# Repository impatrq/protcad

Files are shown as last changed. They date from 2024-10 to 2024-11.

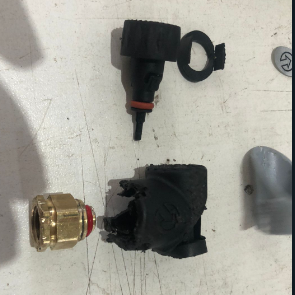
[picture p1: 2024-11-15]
Captura de pantalla 2024-11-15 102701.png

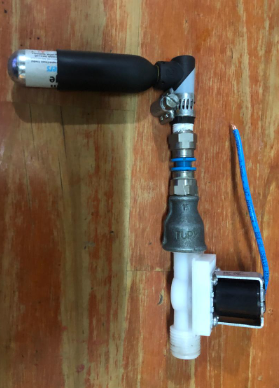
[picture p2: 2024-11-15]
Captura de pantalla 2024-11-15 101422.png

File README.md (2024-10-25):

# protcad

PRESENTACION DEL PROYECTO:

Es un proyecto, desarrolamos un sistema de seguridad automatico,
pensado principalmente para adultos mayores, para personals en
reabilitacion, o que sufren de anguna enfermedad o son epilepticos
es un chaleco tipo airbag que amortigua las caidas al inflarse

roblemas clave: 
Lesiones Graves / Muerte: Las caídas pueden resultar en fracturas y otros daños que limitan la movilidad y la independencia. 
Miedo y Ansiedad: Muchas personas mayores y sus familias viven con el miedo constante de que una caída pueda causar un accidente grave. 
Dependencia Aumentada: Después de una caída, algunas personas necesitan más ayuda, lo que puede afectar su autonomía. 
Costos Médicos: Las lesiones por caídas generan gastos altos en tratamientos médicos y hospitalizaciones. 
 
 Lesiones: Aproximadamente el 30-40% de las personas mayores de 65 años sufren caídas anualmente, y un porcentaje considerable de estas caídas resultan en lesiones. 
Muertes: Las caídas son una de las principales causas de muerte accidental en personas mayores. En Estados Unidos, por ejemplo, se estima que alrededor de 36,000 personas mayores mueren anualmente debido a caídas. 

La solucion que ofrece ProtCad

1. deteccion rapida de las caidas 
Utiliza el sensor MPU6050 para monitorear continuamente la posición y aceleración del usuario. Al detectar una inclinación que indica una caída, el sistema se activa de inmediato.
2. Inflado Automático del Airbag:
Al activarse, un cartucho de CO2 infla rápidamente una bolsa protectora alrededor de áreas vulnerables, como la cadera, amortiguando el impacto y reduciendo el riesgo de lesiones graves.
3. Protección de Áreas Críticas:
El diseño del chaleco está enfocado en proteger las zonas más susceptibles a fracturas, lo que ayuda a prevenir lesiones graves en caso de caídas.
4. Tranquilidad para Usuarios
proporciona seguridad tanto al usuario como a sus familiares, aliviando la ansiedad relacionada con las caídas y fomentando la independencia en las actividades diarias.

OBJETIVOS:
Dar protección, seguridad, minimizar el riesgo de lesiones graves por caídas en personas mayores y con condiciones de movilidad reducida, mejorando así su seguridad y calidad de vida.

1. Prevención de Lesiones:Que nuestros usuarios puedan tener una mejor calidad de vida.

2. Detección Precisa de Caídas: Tener un sistema seguro y con la mejor presicion.

3. Facilitar la Independencia.

4. Tranquilidad para Cuidadores y Familiares.

5. Evaluación y Mejora Continua.

Publico Objetivo:

En Argentina el 15,7% de la poblacion son adultos mayores que es nuestro principal interes desp estan las personas en reabilitacion.

El segmento destino de ProtCad se enfoca principalmente en las siguientes 
usuarios:

1. Personas mayores de 40 años: A partir de esta edad, los huesos 
tienden a volverse más frágiles debido a la disminución de la densidad 
ósea y la pérdida de calcio. Esto las hace más vulnerables a fracturas 
graves en caso de caídas, especialmente en la cadera. Este grupo es el 
más susceptible a sufrir consecuencias graves, como dificultades de 
movilidad, pérdida de independencia, o incluso muerte por 
complicaciones derivadas de una fractura de cadera.

2. Personas en rehabilitación: Aquellas que se recuperan de una cirugía 
o lesión y que necesitan protección adicional para evitar recaídas que 
puedan agravar su estado. ProtCad ofrecería una capa extra de 
seguridad durante el proceso de recuperación.

3. Personas con condiciones neurológicas como epilepsia, Parkinson 
o esclerosis múltiple: Estos usuarios están más expuestos a caídas 
debido a problemas de coordinación y equilibrio que son comunes en 
estas condiciones.

4. Personas con enfermedades crónicas como osteoporosis o diabetes 
con neuropatía periférica: Estas condiciones incrementan el riesgo 
de fracturas o lesiones graves en caso de caídas, lo que convierte a ProtCad en una herramienta de protección valiosa para evitar daños mayores.

5. Personas que cuidan a sus seres queridos: Además de los usuarios directos, este segmento incluye a quienes tienen a su cargo personas mayores o con discapacidades, y que buscan mejorar la seguridad y reducir la ansiedad de cuidar a alguien vulnerable a caídas.

En resumen, ProtCad está dirigido a personas de mediana edad y mayores, así como a aquellos con condiciones médicas específicas que los hacen más propensos a sufrir caídas y lesiones severas.

* COSTOS:   

En Japon venden este producto por su gran poblacion de adultos mayores, en europa y Estados unidos tambien, en argentina sale aprox   $ 1.000.000
![]() 

Descripcion Tecnica:
 
Sensores principales que utilizamos: 

* MPU6050: Cuenta con un giroscopo con 3 ejes y un acelerometro de 3 ejes.
* RASPBERRY PICO: Trabajamos con un codigo de lenguaje en C.

FIN.

Lo visto como presentacion es lo que se encuentra ya en un archivo y se presento en la oniet y se presentara en proximas esposiciones en su formato como power point.

A continuacion la siguiente INFORMACION tambien se encuetra en el informe descriptivo

ALCANCE DE PROTCAD:

Alcance: Delimitar el proyecto, y describir de qué trata:
PROTCAD es un chaleco de protección, diseñado para minimizar el impacto 
de caídas y prevenir lesiones graves. El chaleco se activa automáticamente al 
detectar una caída, inflándose de inmediato para proteger áreas clave.
Limitaciones del proyecto:
1. Tamaño único por el momento: Aunque adaptable, actualmente el 
chaleco está disponible en un solo talle general.
2. Enfoque en usuarios específicos: Está dirigido principalmente a 
personas con riesgo de caídas, lo que limita su adopción masiva en 
personas fuera de estos grupos.
3. Costo: El precio de producción estimado es de 140 mil pesos, lo que 
podría limitar su accesibilidad a ciertos mercados.
El proyecto, aunque en sus fases iniciales, tiene el potencial de ser mejorado 
con más recursos y tiempo, permitiendo una mayor adaptabilidad y una posible 
expansión hacia otros sectores o mercados más amplios.

. Temática o Impacto de PROTCAD: Bienestar y Salud / Inovacion

* Impacto Social:

PROTCAD tiene un enfoque directo en la seguridad personal y el bienestar
de personas vulnerables, brindando protección a quienes tienen un mayor riesgo 
de sufrir caídas, como adultos mayores, personas en rehabilitación, y aquellos 
con condiciones médicas que afectan su movilidad. 

Su impacto social es significativo por varias razones:
1. Prevención de lesiones graves: Al reducir el riesgo de fracturas o daños 
en la cabeza, la columna y la cadera, PROTCAD contribuye a mejorar la 
salud y calidad de vida de los usuarios, disminuyendo las posibles 
secuelas físicas de una caída.
2. Tranquilidad para el usuario y su entorno: Muchas personas, 
especialmente familiares o cuidadores, viven con la constante 
preocupación de que un ser querido sufra una caída grave. PROTCAD 
ofrece una solución que genera confianza y paz mental tanto para los 
usuarios como para sus seres cercanos.
3. Mejor calidad de vida: El chaleco permite que los usuarios mantengan 
su independencia y realicen sus actividades cotidianas sin temor a sufrir 
un accidente. Esto es crucial para mantener la autonomía y reducir la 
dependencia de terceros, lo cual es particularmente importante para 
personas mayores.
4. Inclusión: PROTCAD se dirige a diversos grupos que enfrentan 
dificultades diarias debido a su condición física, creando un dispositivo 
que ayuda a mejorar la seguridad y el movimiento, dándoles una mayor 
oportunidad de participación en la sociedad.

{Creado en china, desarrollado en EE. UU, disponibles en mercados europeos, america del norte, en Italia, Se espera que su adopción aumente a medida que se vuelvan más accesibles, particularmente en sociedades que envejecen como Japón, Estados Unidos y partes de Europa.}

* Impacto Geográfico 

El impacto geográfico de PROTCAD puede ser relevante tanto a nivel local como global:

1. Impacto Nacional: El proyecto es una innovación que, hasta ahora, no ha sido producida ni distribuida a nivel nacional. Al implementarse en un mercado local, podría cubrir una necesidad significativa en países o regiones con poblaciones envejecidas o con altos índices de 
enfermedades crónicas que afectan la movilidad, como ocurre en muchos países latinoamericanos, incluido Argentina.

2. Impacto Global: A largo plazo, PROTCAD tiene potencial para 
expandirse internacionalmente, ya que el envejecimiento de la población es una tendencia mundial, y con ello aumenta el riesgo de caídas y 
lesiones graves. Países con un mayor porcentaje de personas mayores, como
Japón o algunos países de Europa, serían mercados donde este tipo de
tecnología podría tener una alta demanda.

* Otros Impactos Potenciales

• Sector salud: PROTCAD puede reducir la demanda en los sistemas de 
salud pública y privada al disminuir el número de hospitalizaciones 
relacionadas con caídas, fracturas y cirugías resultantes de accidentes en 
personas mayores o en rehabilitación.
• Innovación tecnológica: Al ser un producto que involucra tecnología 
avanzada (sensores, válvulas, CO2), PROTCAD impulsa la innovación
en el campo de los dispositivos de seguridad personal, contribuyendo al 
desarrollo de nuevos productos que podrían aplicarse en otras áreas o 
grupos.

En resumen, el impacto de PROTCAD es amplio tanto a nivel social como geográfico, ofreciendo una solución que responde a una necesidad urgente en la prevención de lesiones graves por caídas, con el potencial de beneficiar a individuos y sistemas de salud tanto local como globalmente

* Segmento destino (target)

El segmento destino de ProtCad se enfoca principalmente en las siguientes 
usuarios:

1. Personas mayores de 40 años: A partir de esta edad, los huesos 
tienden a volverse más frágiles debido a la disminución de la densidad 
ósea y la pérdida de calcio. Esto las hace más vulnerables a fracturas 
graves en caso de caídas, especialmente en la cadera. Este grupo es el 
más susceptible a sufrir consecuencias graves, como dificultades de 
movilidad, pérdida de independencia, o incluso muerte por 
complicaciones derivadas de una fractura de cadera.

2. Personas en rehabilitación: Aquellas que se recuperan de una cirugía 
o lesión y que necesitan protección adicional para evitar recaídas que 
puedan agravar su estado. ProtCad ofrecería una capa extra de 
seguridad durante el proceso de recuperación.

3. Personas con condiciones neurológicas como epilepsia, Parkinson 
o esclerosis múltiple: Estos usuarios están más expuestos a caídas 
debido a problemas de coordinación y equilibrio que son comunes en 
estas condiciones.

4. Personas con enfermedades crónicas como osteoporosis o diabetes 
con neuropatía periférica: Estas condiciones incrementan el riesgo 
de fracturas o lesiones graves en caso de caídas, lo que convierte a 
ProtCad en una herramienta de protección valiosa para evitar daños 
mayores.

5. Personas que cuidan a sus seres queridos: Además de los usuarios 
directos, este segmento incluye a quienes tienen a su cargo personas 
mayores o con discapacidades, y que buscan mejorar la seguridad y 
reducir la ansiedad de cuidar a alguien vulnerable a caídas.
En resumen, ProtCad está dirigido a personas de mediana edad y mayores, así 
como a aquellos con condiciones médicas específicas que los hacen más 
propensos a sufrir caídas y lesiones severas.

* Ámbito de incumbencia (entorno donde se desarrolla) 

El ámbito de incumbencia de ProtCad se centra en varios entornos 
clave donde este producto podría desarrollarse y tener impacto:

1) Sector de la salud y rehabilitación: ProtCad se inserta dentro 
de la atención médica preventiva, especialmente en centros de 
rehabilitación, hospitales, y clínicas donde se tratan personas 
con condiciones físicas que las hacen propensas a caídas, como 
pacientes geriátricos o aquellos en procesos postoperatorios. 
Además, tiene cabida en instituciones especializadas en 
neurología para personas con Parkinson, epilepsia o esclerosis 
múltiple.
2) Hogares de cuidado de ancianos y residencias geriátricas: 
Los hogares de cuidado, donde la preocupación por caídas es 
alta, son un entorno esencial para la implementación de 
ProtCad. En estos espacios, los cuidadores y personal médico 
buscan maneras de mejorar la seguridad de las personas 
mayores, y este tipo de tecnología sería un complemento ideal 
para reducir riesgos.
3) Entornos domésticos: Para personas que envejecen en sus 
propios hogares, el chaleco ProtCad ofrece una solución práctica 
para mejorar su seguridad diaria sin comprometer la 
independencia. Familias que cuidan a personas mayores o con 
movilidad reducida podrían implementar el producto como una 
medida preventiva.
4) Mercado de dispositivos de asistencia personal y tecnología 
vestible (wearables): En el contexto de la tecnología aplicada a 
la salud, ProtCad se integra dentro del mercado de los wearables 
o dispositivos inteligentes de protección. Este tipo de chaleco 
airbag, que combina sensores avanzados con mecanismos 
automáticos de inflado, puede atraer a personas que buscan 
productos de alta tecnología para mejorar su calidad de vida.
5) Industrias de protección laboral: Aunque inicialmente se 
piensa en el sector de la salud, el ámbito laboral para 
trabajadores de ciertos sectores (construcción, agricultura, etc.) 
donde el riesgo de caídas es alto también es relevante. ProtCad 
podría adaptarse a estos entornos, brindando seguridad adicional 
a los trabajadores.

En resumen, el entorno donde se desarrolla el proyecto abarca el 
ámbito sanitario, los hogares de cuidado, y el mercado de 
dispositivos de protección personales, con la posibilidad de 
expandirse a sectores laborales.

Descripción general (Explicar el proyecto) 
ProtCad es un proyecto innovador que busca desarrollar un chaleco (en 
principio era un cinturon) de protección tipo airbag, diseñado para activarse en 
el momento de una caída. Este dispositivo está pensado principalmente para 
personas mayores o con condiciones médicas que las hagan propensas a caídas, 
como osteoporosis, Parkinson o problemas de movilidad. El sistema se activa a 
través de un sensor de movimiento (MPU6050), que detecta la inclinación de la 
persona y libera aire comprimido para inflar una bolsa que protege la cadera y 
otras áreas críticas del cuerpo. El objetivo principal es reducir el impacto y el
riesgo de lesiones graves, proporcionando seguridad y tranquilidad a los 
usuarios y sus familias.

AREA ELECTRONICA (PROGRAMACION)

linea de codigo usada y probada (funciona) 

#include <stdio.h>
#include <math.h>
#include "pico/stdlib.h"
#include "mpu6050.h"

#define SDA_GPIO  4
#define SCL_GPIO  5 
#define LED_PIN_X 14 // Led rojo - Eje XW
#define LED_PIN_Y 15 // Led verde - Eje Y
#define LED_PIN_VALVE 13 // Valvula de agua
#define X_LIMIT 30.20 // Límite de inclinación para el eje X
#define Y_LIMIT 30.20 // Límite de inclinación para el eje Y

int main(void)
{  
    stdio_init_all();
    sleep_ms(1000);

    printf("Inicializando I2C...\n");

    // Inicializacion de I2C
    i2c_init(i2c0, 400000);
    gpio_set_function(SDA_GPIO, GPIO_FUNC_I2C);
    gpio_set_function(SCL_GPIO, GPIO_FUNC_I2C);
    gpio_pull_up(SDA_GPIO);
    gpio_pull_up(SCL_GPIO);

    printf("Inicializando MPU6050...\n");

    // Inicializacion de MPU6050
    mpu6050_init(i2c0, 0x68);
    sleep_ms(2000);

    printf("Who am I = 0x%2x\n", mpu6050_who_am_i());

    // Configuración de los LEDs como salidas
    gpio_init(LED_PIN_X);
    gpio_init(LED_PIN_Y);
    gpio_set_dir(LED_PIN_X, GPIO_OUT);
    gpio_set_dir(LED_PIN_Y, GPIO_OUT);
    gpio_init(LED_PIN_VALVE);
    gpio_set_dir(LED_PIN_VALVE, GPIO_OUT);

    while (true) {

        // Estructura para datos de aceleracion
        mpu_accel_t accel = {0};
        mpu_gyro_t gyro = {0};
        int16_t temp = 0;

        // Leo MPU
        mpu6050_read_accel(&accel);
        mpu6050_read_gyro(&gyro);
        mpu6050_read_temp(&temp);

        // Convertir aceleracion a G(gravedad)
        float ax = (9.81 * (accel.accel_x / 33678.0));
        float ay = (9.81 * (accel.accel_y / 32768.0));
        float az = (9.81 * (accel.accel_z / 32768.0));

        //Calcular los angulos de inclinacion
        float accel_ang_x = atan(ax / sqrt(pow(ay, 2) + pow(az, 2))) * (180.0 / 3.14);
        float accel_ang_y = atan(ay / sqrt(pow(ax, 2) + pow(az, 2))) * (180.0 / 3.14);
        // Muestro valores de aceleracion y angulos de inclinacion
        printf("Ax = %.2f, Ay = %.2f, Az = %.2f\n", ax, ay, az);
        printf("Inclinacion en X: %.2f\tInclinacion en Y: %.2f\n", accel_ang_x, accel_ang_y);
        printf("Temp = %d\n", temp);

        // Verificar si la inclinación en X supera el límite y controlar el LED rojo
        bool led_x_on = fabs(accel_ang_x) > X_LIMIT;
        gpio_put(LED_PIN_X, led_x_on);

        // Verificar si la inclinación en Y supera el límite y controlar el LED verde
        bool led_y_on = fabs(accel_ang_y) > Y_LIMIT;
        gpio_put(LED_PIN_Y, led_y_on);

        // Controlar la válvula: se abre si cualquier LED está encendido
        if (led_x_on || led_y_on) {
            gpio_put(LED_PIN_VALVE, 1);  // Abrir la válvula
        } else {
            gpio_put(LED_PIN_VALVE, 0);  // Cerrar la válvula
        }

        // Pausa de 100 ms entre lecturas
        sleep_ms(1000);
    }
}

Protcad es un chaleco de seguridad tipo airbag que se infla al reconocer que el usuario se esta por caer. Esta dirigido a personas en rehabilitacion, gente mayor, y personas que sufran algun tipo de condicion propensa a sufrir caidas. El sistema consta de un sensor MPU6050 acelerometro y giroscopo que sensa constantemente la condicion del chaleco, en el segundo que la persona se cae, este manda una señal que activa un sistema de abertura de cartuchos de aire comprimido que inflan el airbag que se encuentra dentro del chaleco, haciendo que este este quede totalmente inflado y pueda reducir considerablemente el impacto de la persona contra el suelo

FUNCIONALIDADES Y BENEFICIOS: 

 Funcionalidades (Qué hace?)  

Detección de Caídas: Utiliza un sensor MPU6050 que funciona como giróscopo y acelerómetro para detectar cambios en la posición del usuario, estos son monitoreados continuamente. Cuando el sensor detecta una inclinación que supera los límites predefinidos (indicando una posible caída), activa el sistema de protección. 

Activación Automática del Airbag: Al detectar una caída, el sistema abre un cartucho de aire comprimido que infla rápidamente una bolsa alrededor de la cadera, amortiguando el impacto y reduciendo el riesgo de lesiones graves. 

Protección de Zonas Vulnerables: El diseño del chaleco está enfocado en proteger principalmente la cadera, una de las áreas más susceptibles a fracturas en personas mayores o con movilidad reducida, pero también ofrece protección a otras zonas del cuerpo según el diseño. 

Indicadores Visuales: Dispone de luces LED para indicar el estado del dispositivo y alertar sobre el funcionamiento del sensor, mostrando si un eje (X, Y o Z) ha superado los límites de inclinación. 

Botón de Encendido y Apagado: Para mayor control, el usuario puede activar o desactivar el dispositivo cuando lo considere necesario. 

Beneficios (Por qué es bueno el proyecto?)  

1. Prevención de Lesiones: Al proporcionar un sistema de protección tipo airbag que se activa durante una caída, ProtCad reduce significativamente el riesgo de fracturas en la cadera y otras lesiones graves en personas mayores o con problemas de movilidad, evitando hospitalizaciones prolongadas y complicaciones de salud. 

2. Mayor Seguridad y Tranquilidad: Al proteger áreas vulnerables como la cadera, brinda seguridad tanto al usuario como a su entorno cercano (familia, cuidadores), aliviando el miedo y la ansiedad relacionados con caídas. 

3. Innovación y Accesibilidad: El uso de sensores y tecnología de inflado rápida permite una solución avanzada y eficiente que no requiere de intervenciones médicas complicadas. Además, su diseño adaptable lo hace accesible para una amplia gama de personas. 

4. Mejora de la Calidad de Vida: Al reducir el impacto de las caídas, ProtCad permite que las personas mayores o en rehabilitación puedan moverse con más libertad, confianza e independencia, promoviendo una vida más activa y saludable. 

5. Costo Eficiente: En comparación con los costos médicos de tratar fracturas y otros daños, el uso preventivo de ProtCad es una inversión rentable a largo plazo para evitar gastos médicos elevados.

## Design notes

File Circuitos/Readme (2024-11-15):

En esta carpeta se encuentra todo lo relacionado a circuitos

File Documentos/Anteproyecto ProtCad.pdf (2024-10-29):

# ProtCad

# Anteproyecto

# Título de proyecto:

El nombre “ProtCad” es una abreviación del nombre “Protección de Cadera”

# Integrantes:

- Micaela, Lopez Arana
- Dafne, Monzon Matos

# Objetivo del proyecto:

Diseñar y construir un cinturón de protección para personas que, al momento de caerse y recibir un fuerte golpe en la zona de la cadera, se active un sistema que rodee la cadera de la persona con bolsas de aire que amortigüe el cuerpo al momento del impacto.

# Utilidades del proyecto:

ProtCad está derivado a gente arriba de los 45, debido que a partir de esta edad los huesos empiezan a volverse más débiles por la fata de calcio y fosforo. Desde cierta edad, los huesos al estar más débiles sufren desgastes, con una caída podría ocasionar graves lesiones , se ha visto que la cadera es de los lugares del cuerpo que más suelen recibir golpes severos.

Recibir un golpe en esta zona puede causar:

- Dolor muscular
- Dificultad para caminar, perdida de movilidad

- Perdida de independencia
- Lesiones
- Acortar la vida
- La muerte

Los golpes en esta zona son los más recurrentes y uno de los más serios, puede causar una gran problemática en la vida diaria tanto para la persona como para quienes la rodean. Aunque esto se dedica a alguien mayor de 45 años, se espera un mayor uso en personas con problemas al caminar (con mayor índice de posibles caídas), en su momento se espera que se pueda actuar y asegurar que la persona no sufrió daños severos.

Nuestro proyecto busca dar seguridad a quien lleve este cinturón, confiando y buscando tener en cuenta la comodidad y confianza del individuo, a su vez buscamos aligerar el estrés de la persona y de quienes lo rodeen y evitar daños a futuro en quienes lo utilicen.

# Descripción del funcionamiento:

Lo fundamental en este proyecto, es el sensor MPU6050 que vamos a usar como giróscopo, así pudiendo determinar los puntos de caída que tiene una persona gracias a sus tres ejes (X, Y, Z).

Se divide en dos partes, el circuito de detección del sensor mpu6050, y el sistema que abre el cartucho de aire para que se infle el cinturón.

Se piensa usar Raspberry pi pico o ver de usar un ESP32 que podria tener mas desarrollo.

Parte del Sensor MPU6050:

Primero conectamos el sensor al microcontrolador y a su vez conectamos 3 leds de diferente color (rojo, verde, azul) para diferencias los ejes del sensor (Y, X, Z), los cuales también tienen una resistencia de 100 ohms cada uno.

Ajustando en el código del sensor, se definen los límites de los grados de cada eje, los leds aparte de servir para diferenciar cada eje se van a activar siempre que un eje supere su límite de grados, por ejemplo, si el eje Y supera los -10° se va a encender el led verde, si el eje X los supera, se va a encender el led azul, y si el eje Z los supera, se va a encender el led rojo. Esto se toma como una ayuda para poder ir definiendo los límites del sensor y cómo reacciona ante los movimientos y las diferentes posiciones que se pueden tener.

Parte del cartucho de aire:

El sistema que se piensa crear es un motor dc n20 para que al girar accione una aguja que se mueva unos pocos centímetros hasta perforar la tapa de un cartucho de aire que al liberarse la tapa se infle instantáneamente el protector de cadera (echa de nylon y cubierta de tela para mayor seguridad).

Para esto se piensa tal vez usar a su vez otro motor que active otra válvula de aire, ya que se emplearan dos válvulas de aire para llenar todo el protector y no solo una, a su vez existe la posibilidad de usar un solo motor buscando la manera de perforar más de un cartucho.

Conjunto de ambas partes:

En esta parte tenemos que unir ambos espacios, definiendo que cuando un led se encienda indicando que la persona sobrepaso el límite de grados(caerse) active el motor dc n20 y abra el cartucho dejando que el protector se llene por completo y pueda amortiguar la caída de dicha persona. Después de programar el sensor MPU6050 a su vez se ira programando el motor Dc20, pero se separa en partes para una mejor organización por más que esto se trabaje en conjunto.

Cinturón:

Se usará un cinturón que se pueda abrochar a la altura de la cadera o el ombligo y sea posible ajustarlo o desajustarlo, estará compuesto con bolsas de nylon rodeando un poco la cadera y un compartimiento para el circuito con su respectiva fuente recargable, y los compartimientos para los cartuchos de aire que trataran de ser cambiables.

# Análisis de factibilidad:

Se cuenta con herramientas y conocimientos básicos para realizar este proyecto, también se considera la falta de conocimiento muy importante en este tema, habiendo investigado se pudo finalizar que la información que nos falta está disponible para investigación y explicación en lo que necesitemos, al igual que los seguros problemas que surjan en este tramo se espera contar con el apoyo de los profesores en cuestión de dudas y recomendaciones.

Todos los integrantes del grupo trabajaran en los mismos campos de trabajo constantemente, pero se podría tener una guía de que haría cada uno:

Micaela Lopez Arana:

.Se encargara de la programación del Sensor MPU6050

.Investigación de los cartuchos de Co2 en conjunto con el airbag necesario

.Diseño de planos de placas , PCB y realización de circuitos, de motor mpu6050 su diseño de circuito electronico

.Creación de cuentas de correo electronico

.Creacion y ensamblaje principal del cinturon, su diseño

. Informes/registro: en formato borrador de los procesos que se realizan para tener su registro y proceso durante el año.

Dafne Monzon Matos:

.Redactar el manual de usuario: los borradores del proceso del proyecto durante el año eh informes diarios del progreso de el mismo para tener un registro, y a fin de año un manual final que sería el oficial.

. Programación del motor en conjunto al Sensor MPU6050, ósea su programación y ensamblaje con la otra parte del sensor mpu6050

. impresión de piezas 3D: de ser necesarias, y ayuda con la obtención o compras de componentes

. Creación del logo (en conjunto), distintivos y ej: remeras

. Marketing: diseño y creación de las páginas web, publicidad en redes sociales con información sobre ProdCad

. Ensamblaje de componentes: ayuda con la creacion del cinturon y soldadura de placas etc

. Guia grafica de procesos a hacer durante el año y desarrollo de procesos

# Costo del proyecto:

Componente | Precio | Disponible
2 sensores MPU6050 | 2.000$ 5.000$ | Si
Rapberry Pi Pico | | Si
Protoboard | 2.000$ 3.000$ | Si
Modulo Rele 2 Canales | 5.000$ 8.000$ | Si
Tres resistencias de 100 ohms | 1.000$ 2.000$ | Si
Motor Dc N20 | 4.000$ 6.000$ | Si
Power Bank | 20.000$ | Si
Nylon | | Si
Jumpers | 2.000$ 3.000$ | Si
3 leds | | Si

Costo total aproximado del proyecto:

- 50.000$(Sumando el valor mas caro)
- 65.000$(Agregando componentes propios)

Todos estos productos fueron buscados en Mercado Libre para una mejor referencia, aun asi se pueden encontrar lugares que reducirían el costo de muchos de estos productos, pudiendo así reducir el costo total del proyecto.

# Referencias:

- https://www.google.com/url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 (https://www.todomicro.com.ar/arduino/176-acelerometro-y-giroscopio-mpu-6050.html)
- https://articulo.mercadolibre.com.ar/MLA-1406668761-sensor-modulo-acelerometrogiroscopio-6-ejes-mpu6050-arduino-_JM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 (https://articulo.mercadolibre.com.ar/MLA-1406668761-sensor-modulo-acelerometro-giroscopio-6-ejes-mpu6050-arduino-_JM)
- https://www.mercadolibre.com.ar/placa-desarrollo-raspberry-pi-pico-w-rp2040-conwifi/p/MLA34289250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 (https://www.mercadolibre.com.ar/placa-desarrollo-raspberry-pi-pico-w-rp2040-con-wifi/p/MLA34289250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)
- https://www.mercadolibre.com.ar/placa-experimental-protoboard-830-puntos-arduinoelectronica/p/MLA27915857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 (https://www.mercadolibre.com.ar/placa-experimental-protoboard-830-puntos-arduino-electronica/p/MLA27915857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)
- https://articulo.mercadolibre.com.ar/MLA-927644290-modulo-relay-rele-2-canalesoptoacoplado-12v-arduino-hobb-_JM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 (https://articulo.mercadolibre.com.ar/MLA-927644290-modulo-relay-rele-2-canales-optoacoplado-12v-arduino-hobb-_JM)
- https://articulo.mercadolibre.com.ar/MLA-1103567839-placa-uno-r3-compatible-arduinocon-cable-usb-zocalo-emakers-_JM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 (https://articulo.mercadolibre.com.ar/MLA-1103567839-placa-uno-r3-compatible-arduino-con-cable-usb-zocalo-emakers-_JM)
- https://articulo.mercadolibre.com.ar/MLA-818043421-micro-motor-dc-n20-6v-150rpm-cajareductara-de-6-y-9-volts-
_JM#position=1&search_layout=stack&type=item&tracking_id=31fb140b-bdcf-461a-bea2-0461aada1989 (https://articulo.mercadolibre.com.ar/MLA-818043421-micro-motor-dc-n20-6v-150rpm-caja-reductara-de-6-y-9-volts-_JM)
- https://www.googleadservices.com/pagead/aclk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 &nis=4&ved=2ahUKEwjojJv544CFAxVJqZUCHdj3DfAQ9aACKAB6BAgGEA4&adurl= (https://www.googleadservices.com/pagead/aclk?ai=DChcSEwi_yqH544CFAxWQVUgAHdOiBd8YABANGgJjZQ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)
•
https://click1.mercadolibre.com.ar/mclics/clicks/external/MLA/count?a=UDXSVn%2FZkwXy R3hEv8h4uI6eb0hvr4wp6JGYo6mJPxU7duOto0YVYI4Fg3RKyLkVDaaylWY%2BvATzvDrpOp7w qgN4kYRY31r%2BW%2FS7Z2NAj0HuG8OcQPAf%2FMeH4H4cZHT%2BuxcbSW4zIhrUNAKnl4 DaUwOlQjmrRHqkb8bNs8cIUJacIlyXRc38ylIsxCJWRaH5KeAT03BN9Yu%2FvjaOsqHGm0RoFsp az9ADJKc4B7wlQGKspVq3L8QSU1OHzzyWY8aZsU%2B2zsvP0DvvS0gGhGe6HluF0ZkFMG%2F vO0p6dZYz%2FRhwXZ57V%2FcLRq0bBc33cUAXwPLK7aKSYW6m76y9wpvvEoDlw9d5g9D4oG rJIrRerI4HBQdkyM%2BNzecPLJgar3CZ3gkDsmvUPKQgwjZ7pb4Q4CbjbYt1A%2FjfG3Qut5faEn (https://click1.mercadolibre.com.ar/mclics/clicks/external/MLA/count?rb=x)

sb4IcwccvO72Jzm3i5z49dZ0ubg4K1yc4c0qiglw2MiG7AKe3KSvtoti3jZdxN8rovZBPOP9dibCsBv VKqXFkZlBQuNQ9oNSVtpUmkqUbUIbUNk%2BzurhJYMwMG6tJyo7SI6KWdBAbKGAvdbZx3jH S6A7vVoPGe3uOzypS5xHZnAfSIjzyhOmNZDQGFmx0I0pv1Ltz70tXO1XDGYDsteqJd0UaJERzCu Ja7KUYy0upD8Xh5YjLswevH61we1c607g4rwHa6xl3kXkwxDBe%2FHJD4d91YR44vkS%2F1Qt0 %3D&e=mclics%2Fgtins%2B17001%2Cmclics%2Fadvertising-results-augmenteron%2B15098%2Cmclics%2Fvariant-candidates%2B31710%2Cmclics%2Fsearch-list-adalgorithm%2BDEFAULT%2Cmclics%2Fmax-bid-capped%2B36383%2Cmclics%2Fmax-biditem-factor%2B23927%2Cmclics%2Fpads-score-mla%2B17263%2Cmclics%2Flax-topdomain%2B23443&rb=x (https://click1.mercadolibre.com.ar/mclics/clicks/external/MLA/count?rb=x)
•

# Analisis de costo/beneficio:

Este proyecto esta derivado a gente mayor de 40 años, que es la edad en adelante en las que los huesos se empiezan a volver más débiles siendo propenso a más riesgos. Puede ser usado por quien lo crea adecuado si lo necesita, gracias a eso puede ser usado por una gran variedad de personas para poder protegerse de una forma mas segura para evitar riesgos, como personas en rehabilitacion, personas con huesos debiles y demas. Si bien tiene que tener un cierto campo de uso, no tendria restriccion en cuestion de quien desee utilizarlo.

# Diagrama de bloques del prototipo:

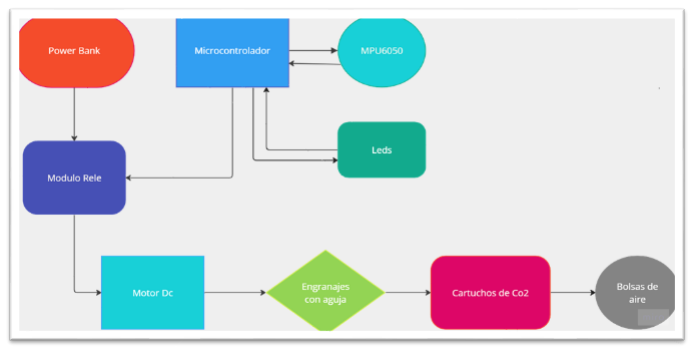
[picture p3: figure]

# Diagrama de tiempo de desarrollo:

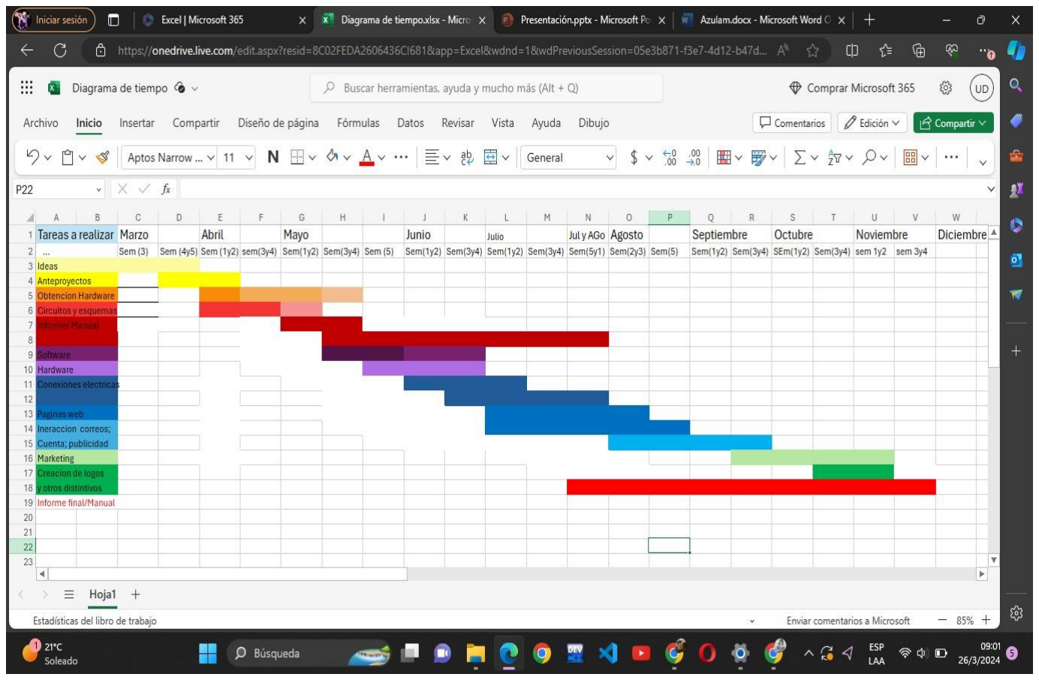
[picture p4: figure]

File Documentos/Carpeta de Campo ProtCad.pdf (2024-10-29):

# CARPETA DE CAMPO

# ProtCad

## Proyecto de 7mo

## IMPA

## Integrantes:

## Lopez Arana Micaela

## Monzon Matos Dafne

# ProtCad

# Anteproyecto

# Título de proyecto:

El nombre “ProtCad” es una abreviación del nombre “Protección de Cadera”

# Integrantes:

- Micaela, Lopez Arana
- Dafne, Monzon Matos

# Objetivo del proyecto:

Diseñar y construir un cinturón de protección para personas que, al momento de caerse y recibir un fuerte golpe en la zona de la cadera, se active un sistema que rodee la cadera de la persona con bolsas de aire que amortigüe el cuerpo al momento del impacto.

Utilidades del proyecto:ProtCad está derivado a gente

arriba de los 45, debido que a partir de esta edad los huesos empiezan a volverse más débiles por la fata de calcio y fosforo. Desde cierta edad, los huesos al estar más débiles sufren desgastes, con una caída podría ocasionar graves lesiones , se ha visto que la cadera es de los lugares del cuerpo que más suelen recibir golpes severos.

Recibir un golpe en esta zona puede causar:

- Dolor muscular
- Dificultad para caminar, perdida de movilidad
- Perdida de independencia
- Lesiones
- Acortar la vida

- La muerte

Los golpes en esta zona son los más recurrentes y uno de los más serios, puede causar una gran problemática en la vida diaria tanto para la persona como para quienes la rodean. Aunque esto se dedica a alguien mayor de 45 años, se espera un mayor uso en personas con problemas al caminar (con mayor índice de posibles caídas), en su momento se espera que se pueda actuar y asegurar que la persona no sufrió daños severos.

Nuestro proyecto busca dar seguridad a quien lleve este cinturón, confiando y buscando tener en cuenta la comodidad y confianza del individuo, a su vez buscamos aligerar el estrés de la persona y de quienes lo rodeen y evitar daños a futuro en quienes lo utilicen.

# Descripción del funcionamiento:

Lo fundamental en este proyecto, es el sensor MPU6050 que vamos a usar como giróscopo, así pudiendo determinar los puntos de caída que tiene una persona gracias a sus tres ejes (X, Y, Z).

Se divide en dos partes, el circuito de detección del sensor mpu6050, y el sistema que abre el cartucho de aire para que se infle el cinturón.

Se piensa usar Raspberry pi pico o ver de usar un ESP32 que podria tener mas desarrollo.

Parte del Sensor MPU6050:

Primero conectamos el sensor al microcontrolador y a su vez conectamos 3 leds de diferente color (rojo, verde, azul) para diferencias los ejes del sensor (Y, X, Z), los cuales también tienen una resistencia de 100 ohms cada uno.

Ajustando en el código del sensor, se definen los límites de los grados de cada eje, los leds aparte de servir para diferenciar cada eje se van a activar siempre que un eje supere su límite de grados, por ejemplo, si el eje Y supera los -10° se va a encender el led verde, si el eje X los supera, se va a encender el led azul, y si el eje Z los supera, se va a encender el led rojo. Esto se toma como una ayuda para poder ir definiendo los límites del sensor y cómo reacciona ante los movimientos y las diferentes posiciones que se pueden tener.

Parte del cartucho de aire:

El sistema que se piensa crear es un motor dc n20 para que al girar accione una aguja que se mueva unos pocos centímetros hasta perforar la tapa de un cartucho de aire que al liberarse la tapa se infle instantáneamente el protector de cadera (echa de nylon y cubierta de tela para mayor seguridad).

Para esto se piensa tal vez usar a su vez otro motor que active otra válvula de aire, ya que se emplearan dos válvulas de aire para llenar todo el protector y no solo una, a su vez existe la posibilidad de usar un solo motor buscando la manera de perforar más de un cartucho.

Conjunto de ambas partes:

En esta parte tenemos que unir ambos espacios, definiendo que cuando un led se encienda indicando que la persona sobrepaso el límite de grados(caerse) active el motor dc n20 y abra el cartucho dejando que el protector se llene por completo y pueda amortiguar la caída de dicha persona. Después de programar el sensor MPU6050 a su vez se ira programando el motor Dc20, pero se separa en partes para una mejor organización por más que esto se trabaje en conjunto.

Cinturón:

Se usará un cinturón que se pueda abrochar a la altura de la cadera o el ombligo y sea posible ajustarlo o desajustarlo, estará compuesto con bolsas de nylon rodeando un poco la cadera y un compartimiento para el circuito con su respectiva fuente recargable, y los compartimientos para los cartuchos de aire que trataran de ser cambiables.

# Análisis de factibilidad:

Se cuenta con herramientas y conocimientos básicos para realizar este proyecto, también se considera la falta de conocimiento muy importante en este tema, habiendo investigado se pudo finalizar que la información que nos falta está disponible para investigación y explicación en lo que necesitemos, al igual que los seguros problemas que surjan en este tramo se espera contar con el apoyo de los profesores en cuestión de dudas y recomendaciones.

Todos los integrantes del grupo trabajaran en los mismos campos de trabajo constantemente, pero se podría tener una guía de que haría cada uno:

Micaela Lopez Arana:

.Se encargara de la programación del Sensor MPU6050

.Investigación de los cartuchos de Co2 en conjunto con el airbag necesario

.Diseño de planos de placas , PCB y realización de circuitos, de motor mpu6050 su diseño de circuito electronico

.Creación de cuentas de correo electronico

.Creacion y ensamblaje principal del cinturon, su diseño

. Informes/registro: en formato borrador de los procesos que se realizan para tener su registro y proceso durante el año.

Dafne Monzon Matos:

.Redactar el manual de usuario: los borradores del proceso del proyecto durante el año eh informes diarios del progreso de el mismo para tener un registro, y a fin de año un manual final que sería el oficial.

. Programación del motor en conjunto al Sensor MPU6050, ósea su programación y ensamblaje con la otra parte del sensor mpu6050

. impresión de piezas 3D: de ser necesarias, y ayuda con la obtención o compras de componentes

. Creación del logo (en conjunto), distintivos y ej: remeras

. Marketing: diseño y creación de las páginas web, publicidad en redes sociales con información sobre ProdCad

. Ensamblaje de componentes: ayuda con la creacion del cinturon y soldadura de placas etc

. Guia grafica de procesos a hacer durante el año y desarrollo de procesos

# Costo del proyecto:

Componente | Precio | Disponible
2 sensores MPU6050 | 2.000$ 5.000$ | Si

Rapberry Pi Pico | | Si
Protoboard | 2.000$ 3.000$ | Si
Modulo Rele 2 Canales | 5.000$ 8.000$ | Si
Tres resistencias de 100 ohms | 1.000$ 2.000$ | Si
Motor Dc N20 | 4.000$ 6.000$ | Si
Power Bank | 20.000$ | Si
Nylon | | Si
Jumpers | 2.000$ 3.000$ | Si
3 leds | | Si

Costo total aproximado del proyecto:

- 50.000$(Sumando el valor mas caro)
- 65.000$(Agregando componentes propios)

Todos estos productos fueron buscados en Mercado Libre para una mejor referencia, aun asi se pueden encontrar lugares que reducirían el costo de muchos de estos productos, pudiendo así reducir el costo total del proyecto.

# Referencias:

- https://www.google.com/url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 (https://www.todomicro.com.ar/arduino/176-acelerometro-y-giroscopio-mpu-6050.html)
- https://articulo.mercadolibre.com.ar/MLA-1406668761-sensor-modulo-acelerometrogiroscopio-6-ejes-mpu6050-arduino-_JM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 (https://articulo.mercadolibre.com.ar/MLA-1406668761-sensor-modulo-acelerometro-giroscopio-6-ejes-mpu6050-arduino-_JM)
- https://www.mercadolibre.com.ar/placa-desarrollo-raspberry-pi-pico-w-rp2040-conwifi/p/MLA34289250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 (https://www.mercadolibre.com.ar/placa-desarrollo-raspberry-pi-pico-w-rp2040-con-wifi/p/MLA34289250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)
- https://www.mercadolibre.com.ar/placa-experimental-protoboard-830-puntos-arduinoelectronica/p/MLA27915857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 (https://www.mercadolibre.com.ar/placa-experimental-protoboard-830-puntos-arduino-electronica/p/MLA27915857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)
- https://articulo.mercadolibre.com.ar/MLA-927644290-modulo-relay-rele-2-canalesoptoacoplado-12v-arduino-hobb-_JM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 (https://articulo.mercadolibre.com.ar/MLA-927644290-modulo-relay-rele-2-canales-optoacoplado-12v-arduino-hobb-_JM)
- https://articulo.mercadolibre.com.ar/MLA-1103567839-placa-uno-r3-compatible-arduinocon-cable-usb-zocalo-emakers-_JM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 (https://articulo.mercadolibre.com.ar/MLA-1103567839-placa-uno-r3-compatible-arduino-con-cable-usb-zocalo-emakers-_JM)
- https://articulo.mercadolibre.com.ar/MLA-818043421-micro-motor-dc-n20-6v-150rpm-cajareductara-de-6-y-9-volts-
_JM#position=1&search_layout=stack&type=item&tracking_id=31fb140b-bdcf-461a-bea2-0461aada1989 (https://articulo.mercadolibre.com.ar/MLA-818043421-micro-motor-dc-n20-6v-150rpm-caja-reductara-de-6-y-9-volts-_JM)
- https://www.googleadservices.com/pagead/aclk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 &nis=4&ved=2ahUKEwjojJv544CFAxVJqZUCHdj3DfAQ9aACKAB6BAgGEA4&adurl= (https://www.googleadservices.com/pagead/aclk?ai=DChcSEwi_yqH544CFAxWQVUgAHdOiBd8YABANGgJjZQ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)
•
https://click1.mercadolibre.com.ar/mclics/clicks/external/MLA/count?a=UDXSVn%2FZkwXy R3hEv8h4uI6eb0hvr4wp6JGYo6mJPxU7duOto0YVYI4Fg3RKyLkVDaaylWY%2BvATzvDrpOp7w qgN4kYRY31r%2BW%2FS7Z2NAj0HuG8OcQPAf%2FMeH4H4cZHT%2BuxcbSW4zIhrUNAKnl4 DaUwOlQjmrRHqkb8bNs8cIUJacIlyXRc38ylIsxCJWRaH5KeAT03BN9Yu%2FvjaOsqHGm0RoFsp (https://click1.mercadolibre.com.ar/mclics/clicks/external/MLA/count?rb=x)

az9ADJKc4B7wlQGKspVq3L8QSU1OHzzyWY8aZsU%2B2zsvP0DvvS0gGhGe6HluF0ZkFMG%2F vO0p6dZYz%2FRhwXZ57V%2FcLRq0bBc33cUAXwPLK7aKSYW6m76y9wpvvEoDlw9d5g9D4oG rJIrRerI4HBQdkyM%2BNzecPLJgar3CZ3gkDsmvUPKQgwjZ7pb4Q4CbjbYt1A%2FjfG3Qut5faEn sb4IcwccvO72Jzm3i5z49dZ0ubg4K1yc4c0qiglw2MiG7AKe3KSvtoti3jZdxN8rovZBPOP9dibCsBv VKqXFkZlBQuNQ9oNSVtpUmkqUbUIbUNk%2BzurhJYMwMG6tJyo7SI6KWdBAbKGAvdbZx3jH S6A7vVoPGe3uOzypS5xHZnAfSIjzyhOmNZDQGFmx0I0pv1Ltz70tXO1XDGYDsteqJd0UaJERzCu Ja7KUYy0upD8Xh5YjLswevH61we1c607g4rwHa6xl3kXkwxDBe%2FHJD4d91YR44vkS%2F1Qt0 %3D&e=mclics%2Fgtins%2B17001%2Cmclics%2Fadvertising-results-augmenteron%2B15098%2Cmclics%2Fvariant-candidates%2B31710%2Cmclics%2Fsearch-list-adalgorithm%2BDEFAULT%2Cmclics%2Fmax-bid-capped%2B36383%2Cmclics%2Fmax-biditem-factor%2B23927%2Cmclics%2Fpads-score-mla%2B17263%2Cmclics%2Flax-topdomain%2B23443&rb=x (https://click1.mercadolibre.com.ar/mclics/clicks/external/MLA/count?rb=x)
•

# Analisis de costo/beneficio:

Este proyecto esta derivado a gente mayor de 40 años, que es la edad en adelante en las que los huesos se empiezan a volver más débiles siendo propenso a más riesgos. Puede ser usado por quien lo crea adecuado si lo necesita, gracias a eso puede ser usado por una gran variedad de personas para poder protegerse de una forma mas segura para evitar riesgos, como personas en rehabilitacion, personas con huesos debiles y demas. Si bien tiene que tener un cierto campo de uso, no tendria restriccion en cuestion de quien desee utilizarlo.

# Diagrama de bloques del prototipo:

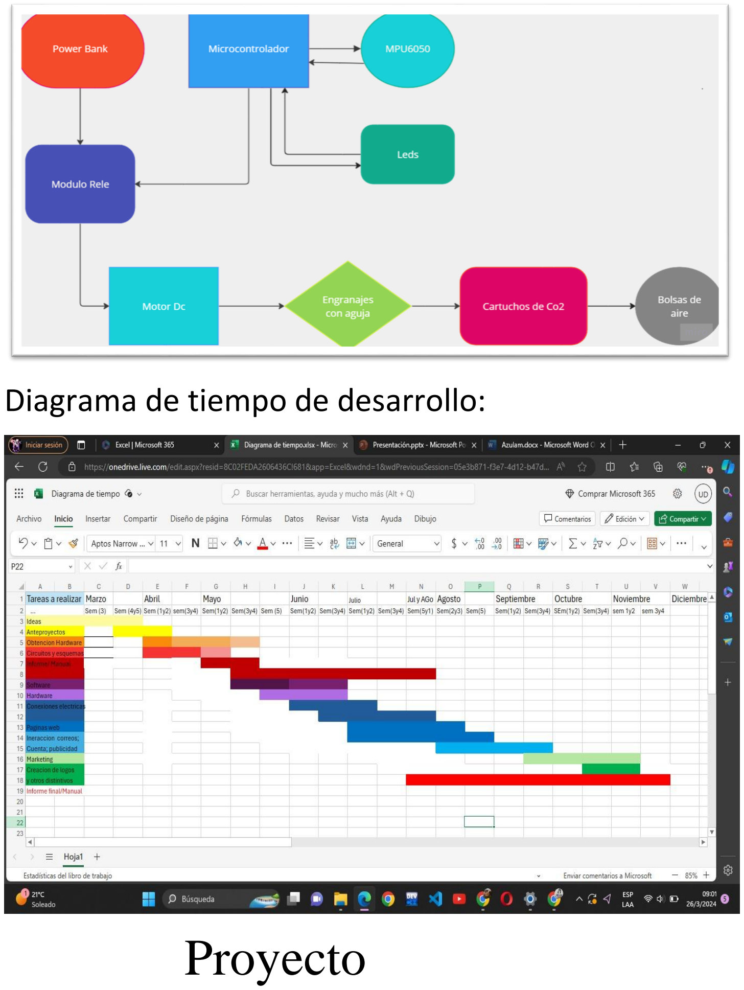
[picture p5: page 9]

# Diagrama de tiempo de desarrollo:

# Proyecto

# Objetivo de proyecto:

Crear un chaleco de seguridad y protección automatico que se active al detectar que el usuario se cae y esta por impactar contra el piso. El chaleco cubre la cadera, la columna, y la cabeza.

# Roles involucrados(Usuarios):

- Personas mayores de 45 años.
- Personas en rehabilitación.
- Personas con problemas en los huesos
- Personas con alguna enfermedad que los vuelve propensos a sufrir caídas o desmayarse(Ejemplo: Epilepsia, Trastornos Psiquiátricos)

# Materiales usados:

Componente | Origen (De donde viene) | Precio
Set de 40 cables macho-macho | Comprado | 3.600$
2 Sensor MPU6050 | Comprado | 7.400$
2 Raspberry Pi Pico | Comprado - Propio | 12.000$ -
Bolsas de plastico de 200 micrones(20) | Propio | -
Bolsas de plastico de 100 micrones(7) | Propio | -
Protoboard | Propio | -
Compus | Propio | -

# Semana 1

# Semana 2

# Semana 3

## Reunion Diaria: 16/04/24

- Se trabaja en el logo
•

# Semana 4

## Reunion Diaria: 17/04/24

- Se define
- Se consiguen bolsas

# Semana 5

## Reunion Diaria: 23/04/24

- Se crea objetivo de usuario
- Charla sobre marketing
- Se ve como redactar correctamente una carta para sposor

# Semana 6

## Reunion Diaria: 30/04/24

- Investigar sobre cargadores de litio

- Dividir areas de software
- Se crea lista de presupuesto de materiales

# Semana 7

## Reunion Diaria: 03/05/24

- Se ven los materiales y comentes que se necesiten a futuro.
- Se investiga sobre cartuchos de aire.

# Semana 8

## Reunion Diaria: 07/05/24

- Se definen mejor las areas de trabajo, como que Dafne se fija mas de los cartuchos de aire y Micaela se fija mas del sensorMPU6050
- Se consigue una bateria de litio.
- Se busca ayuda para poder definir el sistema de abertura de los cartuchos.
- Se redactan cartas para sponsor.

# Semana 9

## Reunion Diaria: 10/05/24

- Se crean diseños para las bolsas de aire
- Se trabaja con la plancha para ver como reacciona el plastico al calor, si bien lo puede sellar, es complicado trabajar con el plastico

# Semana 10

## Reunion Diaria: 14/05/24

- Se trabaja en el codigo del SensorMPU6050 junto a informacion videos pruebas y codigos.
- Se ve un diseño para el prototipo 3 de la bolsa del airbag.
- Se publica informacion del proyecto
- Se ven lugares para obtener los componentes para hacer el pedido de componentes

- Se piden componentes
- Se actualizan fotos de trello
- Se terminan los prototipos de las bolsas de aire, se pudo ver que es complicado trabajar con el material y no es muy conveniente ya que se puede romper facil
Prototipo 1

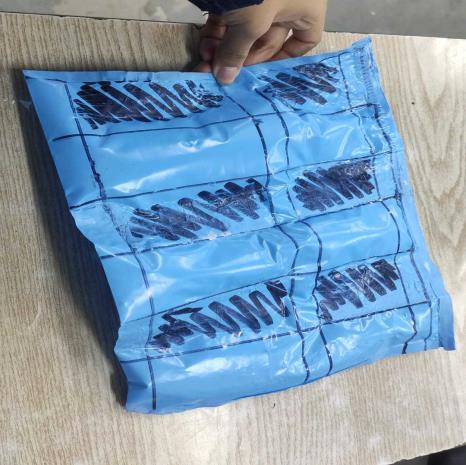
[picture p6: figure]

Prototipo 2

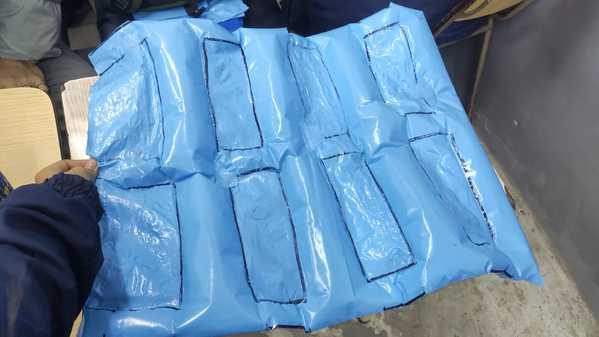
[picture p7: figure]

- Se definen mejor las areas de trabajo

# Semana 11

## Reunion Diaria: 21/05/24

- Se mando mensajes a sponsor de cartuchos de aire
- Gracias a que el material anterior es menos resistente, se usaron bolsas de 200 micrones transparentes para realizar el prototipo 3 del airbag, creando un diseño.
- Se consiguio inflador para poder inflar de forma mas eficaz las bolsas
- A su vez se tiene a disposicion un inflador con manómetro para poder definir la presion de las bolsas para definir que cartuchos usar

# Semana 12

## Reunion diaria: 11/06/24

- Editar publicacion de integrantes
- Se sello el airbag y procedimos a hacer pruebas de caidas para ver si este explotaba. Resultado: No estallo y resistio los impacto sin sufrir un golpe en la zona que lo usabamos. Detalle importante es que se pudo observar que gracias al desbalance es propenso a sufrir un golpe en la zona de la cabeza, esto dio lugar a pensar en otros metodos o diseños mas convenientes.
Prueba de resistencia 1
https://trello.com/1/cards/666756a20e25a47f26b87ed2/attachments/66675aaf1b0aa6f841b82690/download/Video_de_WhatsApp_2024-06-10_a_las_16.55.23_56777f08.mp4 (https://trello.com/1/cards/666756a20e25a47f26b87ed2/attachments/66675aaf1b0aa6f841b82690/download/Video_de_WhatsApp_2024-06-10_a_las_16.55.23_56777f08.mp4)
Prueba de resistencia 2
https://trello.com/1/cards/66675994a5f4723d6d203b7b/attachments/66675b835d1c6c84eb18770f/download/Video_de_WhatsApp_2024-06-10_a_las_16.56.39_bfb72b01.mp4 (https://trello.com/1/cards/66675994a5f4723d6d203b7b/attachments/66675b835d1c6c84eb18770f/download/Video_de_WhatsApp_2024-06-10_a_las_16.56.39_bfb72b01.mp4)
- Se define que en vez de un cinturon que protege la cadera se haga un chaleco que proteja la cadera, la columna, y la cabeza.

# Semana 13

## Reuinion Diaria: 18/06/24

- Se termino la publicacion de integrantes del grupo y se publico

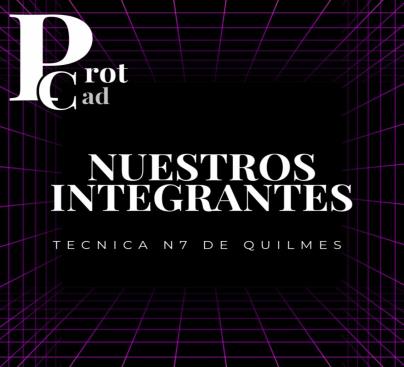
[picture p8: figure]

- Se obtuvieron los materiales principales para trabajar con el SensorMPU6050
- Se armo circuito del sensormpu6050 junto a la raspberry pi pico
- Se siguio trabajando en el codigo del sensormpu6050

# Semana 14

## Reunión Diaria: 28/06/24

- Se eligio un diseño de chaleco como guia para crear nuestro chaleco:

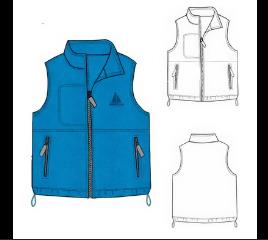
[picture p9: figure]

- Se termino el primer codigo del sensnormpu6050(primer codigo debido a tener que seguir probando si funciona). Se pudo aprender de los errores que saltaban al programar el sensor y lograr obtener valores de los 3 ejes del giroscopo, aun asi no hay seguridad de que este bien por lo que se sigue investigando.
- Se busca una forma de abrir lso cartuchos de aire de forma automatica, como un motor, o inclusive un resorte que imparte con una aguja y perfore los cartuchos.
- Se definieron los cartuchos que vamos a comprar para hacer pruebas
- Se agrego tambien un codigo para el acelerometro en conjunto con el codigo del giroscopo para definir si el giroscopo sensa correctamente, si bien el codigo funciona ante las dudas no se puede definir si sensa correctamente.
- Usando de guia la foto de antes, se hizo un molde en hoja del chaleco buscando el talle M
Prototipo 1

Prototipo 2 – Se definio el talle

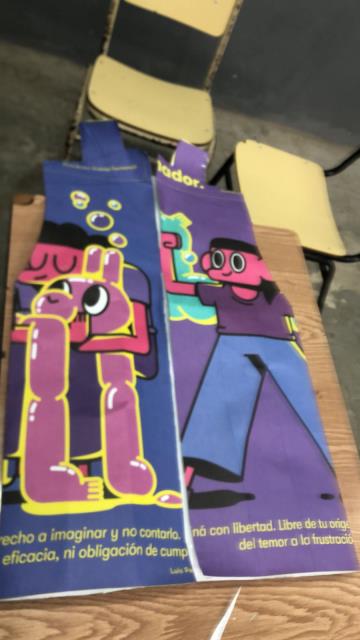
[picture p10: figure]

# Semana 15

30/06/24

- Se estudia codigo del sensor de git hub(Revision de codigo 3)
- Se prueba el plastico y se encuentra la problematica de que no se puede unir con el calor de la plancha

# Semana 16

06/07/24

- Se mantuvo la problematica de que el plastico no se sella con la plancha
- Se investiga y prueba de usar un pegamento para probar si funciona en lugar del plastico(Al final no pega y se intento volver a utilizar la plancha y buscar una solucion)
- Se sigue trabajando en el codigo(Avanzando en lograr terminar de configurar el sensor mpu6050)

# Semana 17

13/08/2024

- Se revisa la lista de compra para agregar o eliminar componentes
- Se soluciona la problemática del sensor MPU6050 con la comuniacion i2C
- Se trata de terminar con el primer dieño del airbag para la cabeza

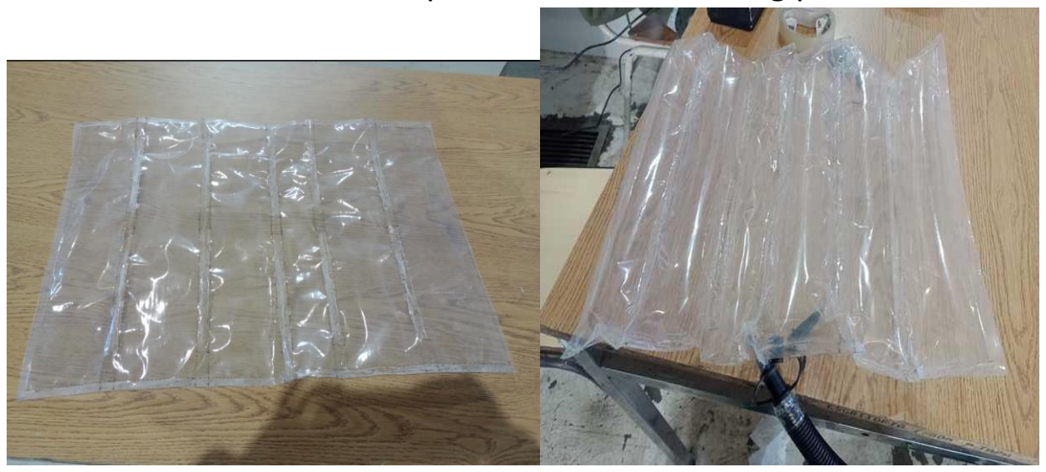
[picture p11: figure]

- Se define una tela a usar en el chaleco
- Se comenzará con la Revisión de código 4. Se seguirá trabando en el código está vez implementando el otro sensor MPU6050 para probar con uno nuevo a diferencia del que ya estábamos usando
- Se pudo seguir programando y se logró solucionar los problemas al censar que tenía el sensor, ahora si bien los valores de temperatura están en un numero exagerado, estos varían correctamente, y los valores de aceleración y del giróscopo se mantiene estables, lo que había que modificar es el sleep que tiene para poder recibir más valores por segundo. Ahora la siguiente etapa es definir las variaciones que tiene un valor de otro para poder identificar el punto en el que el chaleco se tiene que activar.

- Se busca una forma de abrir los cartuchos:

posibles utilidades a investigar: ( pequeños y ligeros serisa lo ideal)

1. How to mount mightyZAP (IR-MB03)
2. Micro 12VDC linear actuator new update
3. cerradura electrica/pestillo
4. Duaitek Micro motor N20-50RPM caja Engranajes Metalica Arduino (6.700 pesos) (se puede transformar en una fuerza lineal)
5. cerradura de puerta electrica. (funciona magneticamente)
6. timbre de escuela ( funciona magneticamente)

*Descartados*

. Mini Taladros

. Pistola recta Ergo pulse PTX

. Los sitmas que utilizan los martillos percutores son efectivos pero son grandes en tamaño y peso.

# Semana 18

20/08/2024

- Hacer diseño del airbag para la zona de a cadera
- Trabajar en el codigo(Revision de codigo 5). Calculos de diferencia de valores

Aca se trabajara en la variacion de valores que recibimos del sensor, pasando a la parte matematica en la que se debera calcular cuando un numero varia de otro y cuanto varia para poder identificar cuando se tiene que activar el sistema.

PROBLEMA: Con el acelerometro puedo medir la inclinacion, y con el giroscopo puede medir la rotacion, esto nos mete en un problema, ya que si bien nos sirve poder medir la inclinaacion, no serviria mucho que este relacionada al acelerometro para que se active de forma automatica.

Despues de estar investigando en diferentes lenguajes y diferentes microcontroladores, hice una prueba de pasar el lenguaje del codigo de un arduino que mide la inclinacion del MPU6050, se trabajo en pasar este codigo a C para trabajarlo e implementar lo necesario al codigo ya propio que tenemos del MPU6050 con la raspberry pi pico.

- Inflado y terminado de plastico para la zona de la espalda

Se encontraron problemas al intentar unir 2 bolsas de plastico para poder hacer una bolsa mas grande, ya que el plastico se rompia y no lograba unirse, despues de intentar diferentes metodos con la plancha y de probar inclusive con pegamento, se fue a trabajar a la base junto con el profesor Bianco para poder preguntar sobre una selladora de plastico que tal vez podrian tener ahi, al tenerlo tuvimos nuevamente problemas para unir el plastico, despues de encontrarle la maña finalmente se pudo sellar y unir ambas bolsas, termine el diseño y ahora pasamos al inflado de dicho plastico. se añadiran datos de si inflado funciona o no funciona.

El airgbag de la espalda se infla correctamente, el unico problema y la unica fuga el el agujero por donde se infla con el inflador, se deberia intentar sellar para probar correctamente que puede protegerte de una caida, y se debera ver si se puede recortar o si no es necesario hacerlo (ya que el airbag tiene que proteger la espalda y no rodearte por completo)

Cabe añadir que tanto el airbag de la cabeza como el airbag de la espalda no sucumbe ante un impacto fuerte por lo que se mantiene inflado correctamente y no se siente el piso al impacto, por lo que solo queda hacer un buen sistema de cerrado de contencion.

- Motor elejido: ( no tiene el torque necesario no sirve)
Datos:

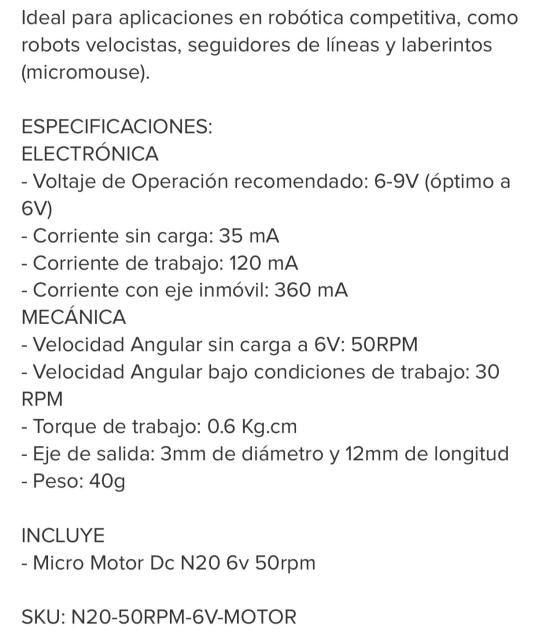
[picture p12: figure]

- Engranajes

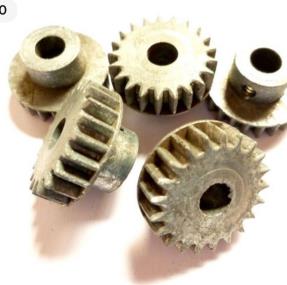
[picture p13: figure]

- Las piezas para el sistema de abertura las vamos a hacer en 3d el piñon y una cremallera que recubra el clavo

# Semana 19

27/08/2024

- Inflado del prototipo del plástico para la zona de la columna
- Se termina el código revisión 5. Censar y probar el cálculo de diferencia.
- prueba del cartucho realizada (cartucho de co2 de 12g)
- compra de cartucho de 16g por un integrante en persona.
- moldes de el diseño del chaleco
- investigación tanto del codigo del sensor mpu como del sistema de abertura del cartucho
- Sistema cremallera para la abertura del cartucho

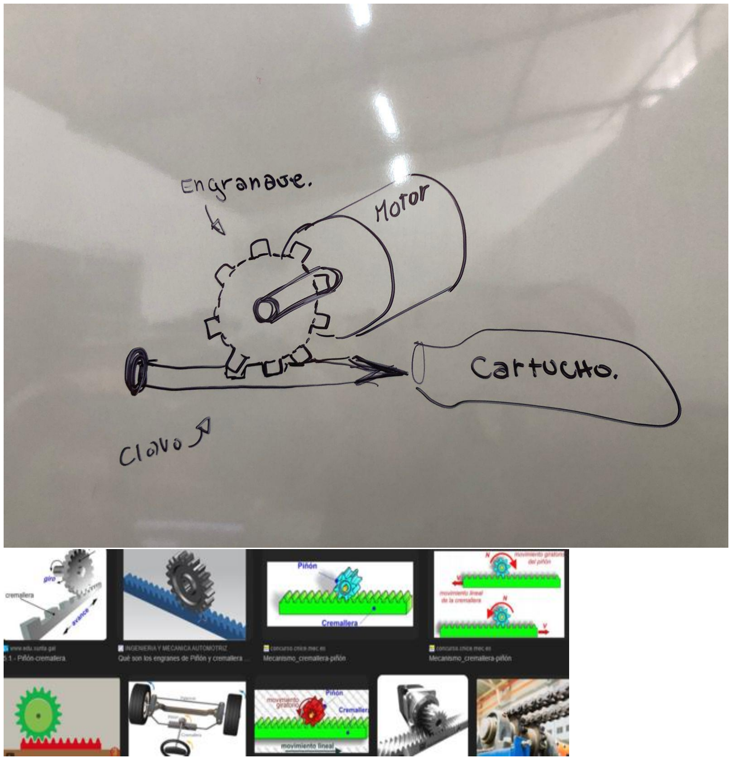
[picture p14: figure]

# Semana 20

03/09/24

- Revision de codigo 6.

Lo que se va a hacer al confirmar que el codigo 5 esta bien, es probar un codigo para activar un led.

Este codigo tiene que constar de ponerle un limite a cada eje de inclinacion(Y - X), haciendo que cuando esto pasa, se prendan dos leds.

Luego de tener problemas de conexion, problemas de valores, y de haber trabajado constantemente, se logro el objetivo.

El codigo implementa el uso de leds, por lo que hay nuevas definciones y tambien los nombres de los limites, que a la vez cada eje no debe superar el limite de 30.20.

Si bien el sensor puede ser muy abrupto al momento de sensar de una manera que puede pasar de una inclinacion de 10 a una de 70, se pudo probar que simulando la rapidez y el cambio de posicion de una caida, esta inclinacion siempre va a superar una inclinacion de 30, por lo que se toma este numero en ambos ejes como limite.

https://trello.com/1/cards/66f1fe936a880c4bc435f0ef/attachments/66f4642ee810b545fe32dac6/download/Video_de_WhatsApp_protcad_2.mp4 (https://trello.com/1/cards/66f1fe936a880c4bc435f0ef/attachments/66f4642ee810b545fe32dac6/download/Video_de_WhatsApp_protcad_2.mp4)

https://trello.com/1/cards/66f1fe936a880c4bc435f0ef/attachments/66f463f9f2ff79074846b93d/download/Video_de_WhatsApp_protcad.mp4 (https://trello.com/1/cards/66f1fe936a880c4bc435f0ef/attachments/66f463f9f2ff79074846b93d/download/Video_de_WhatsApp_protcad.mp4)

# Semana 20

10/09/24

- Se ve la posibilidad de usar un inyector automotriz para los cartuchos de aire.

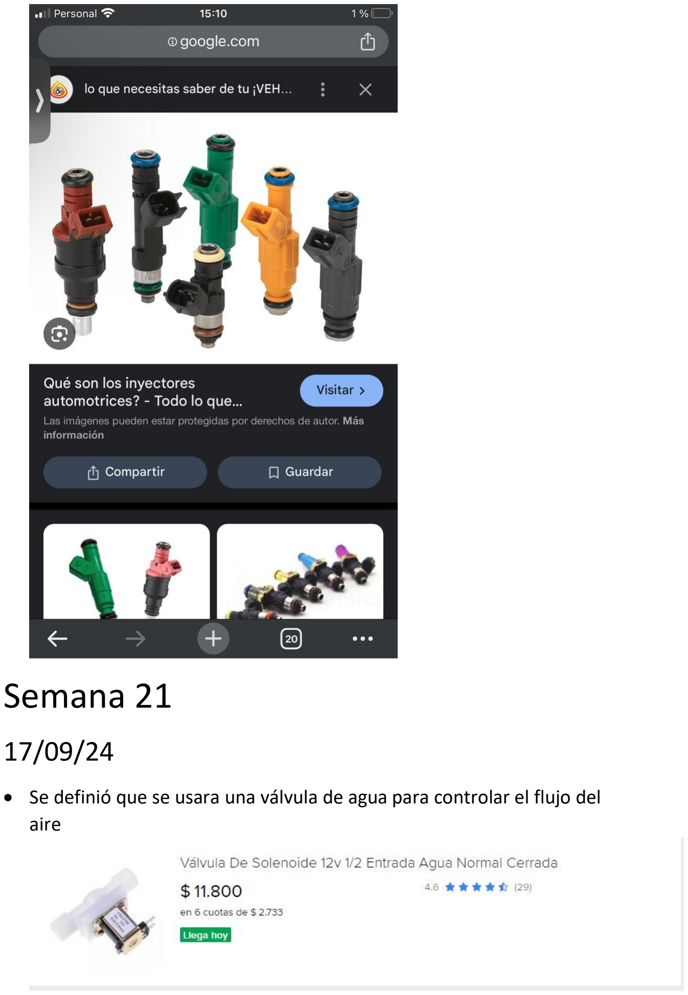
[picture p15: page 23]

# Semana 21

17/09/24

- Se definió que se usara una válvula de agua para controlar el flujo del aire

- Se hace un banner para llevar a las ONIET
- Se trabaja en el circuito para conseguir que se active un led cuando se supera cierta inclinación

# Semana 22

24/09/24

- Se consigue chaleco

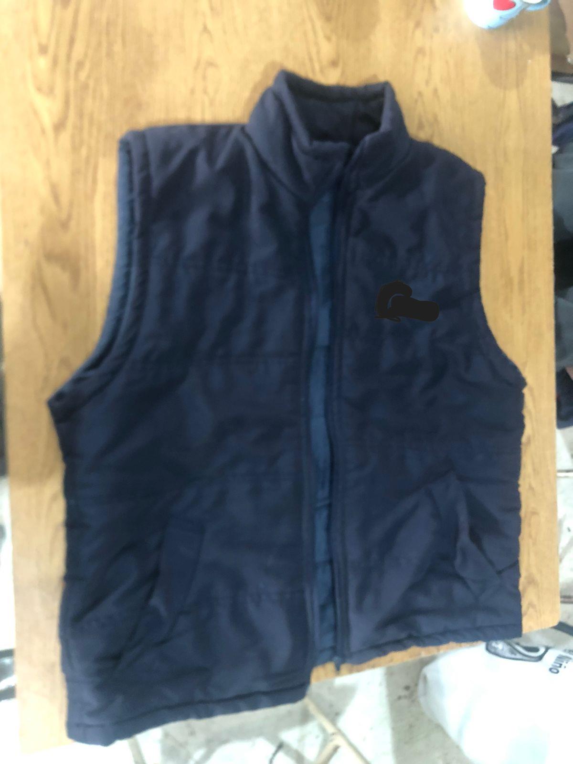
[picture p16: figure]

- Se termina banner

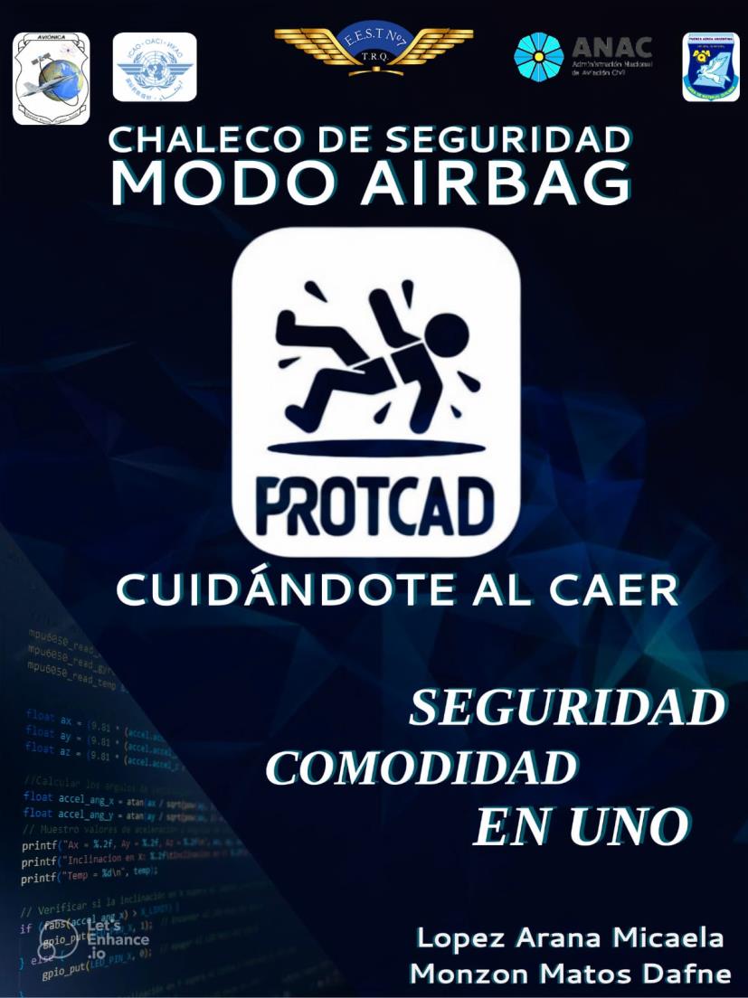
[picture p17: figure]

# Semana 23

01/10/24

- Se logra que al superar cierta inclinacion se prenda un led, pero se debe esperar a que compren la valvula de agua para usarla en definitiva con esta
- Se termina la capucha

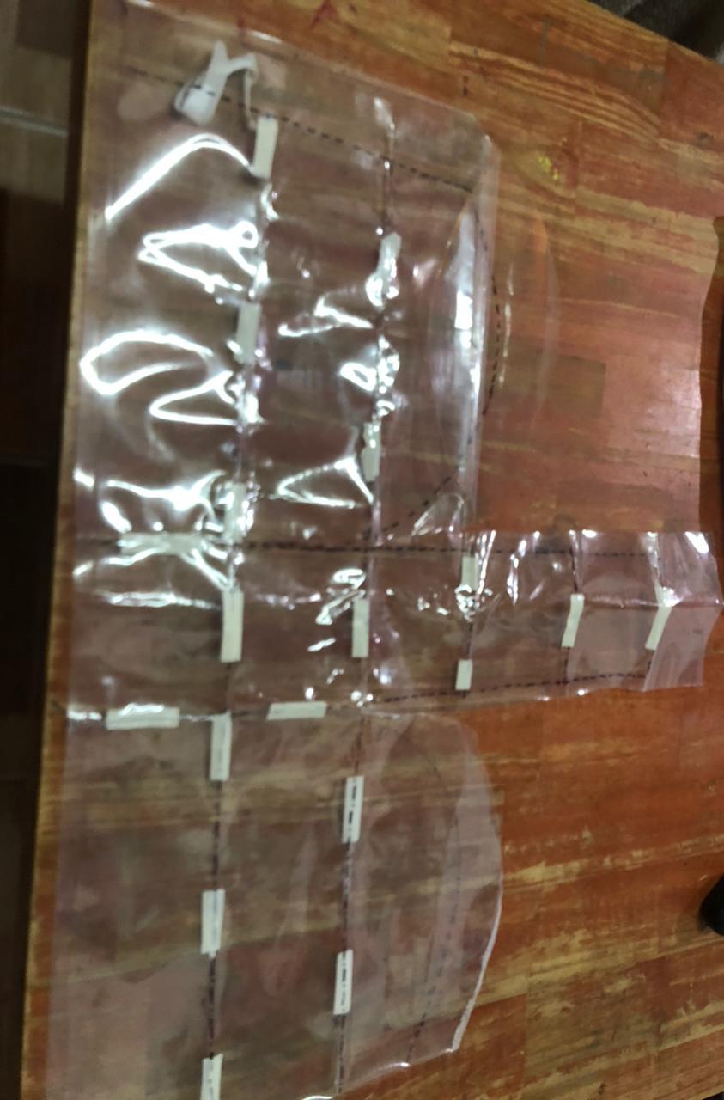
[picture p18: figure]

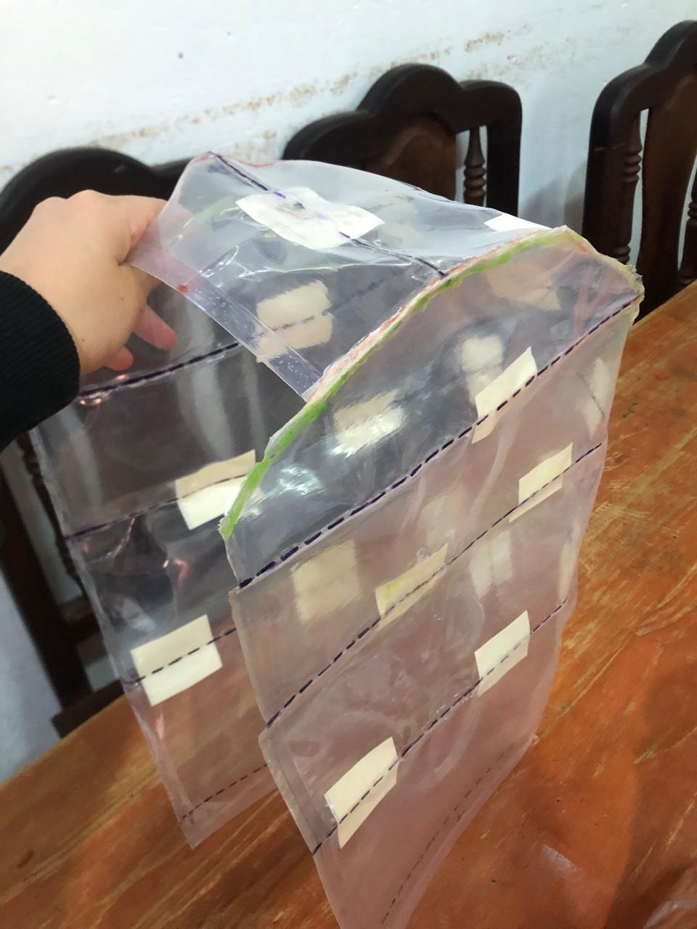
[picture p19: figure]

- Se crea un nuevo diseño a base de rombos

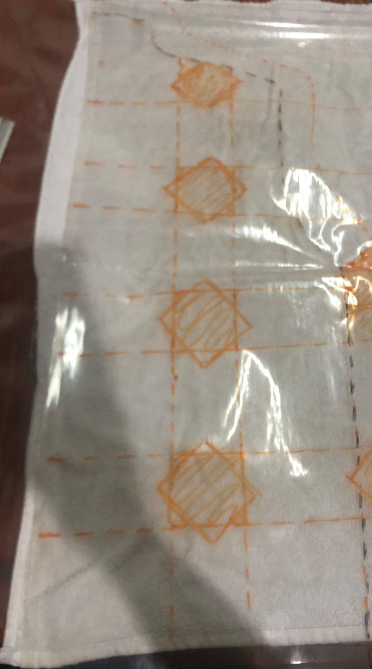
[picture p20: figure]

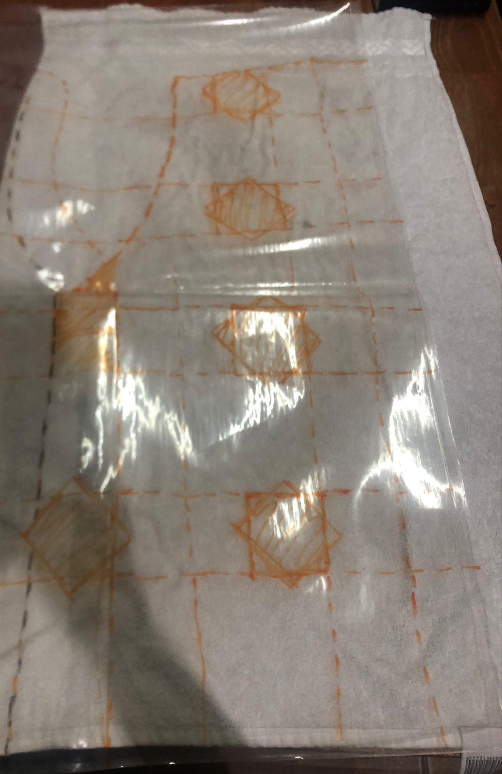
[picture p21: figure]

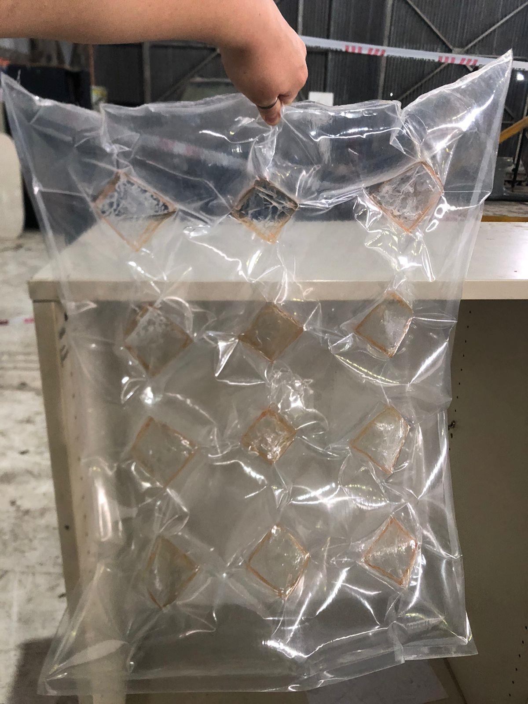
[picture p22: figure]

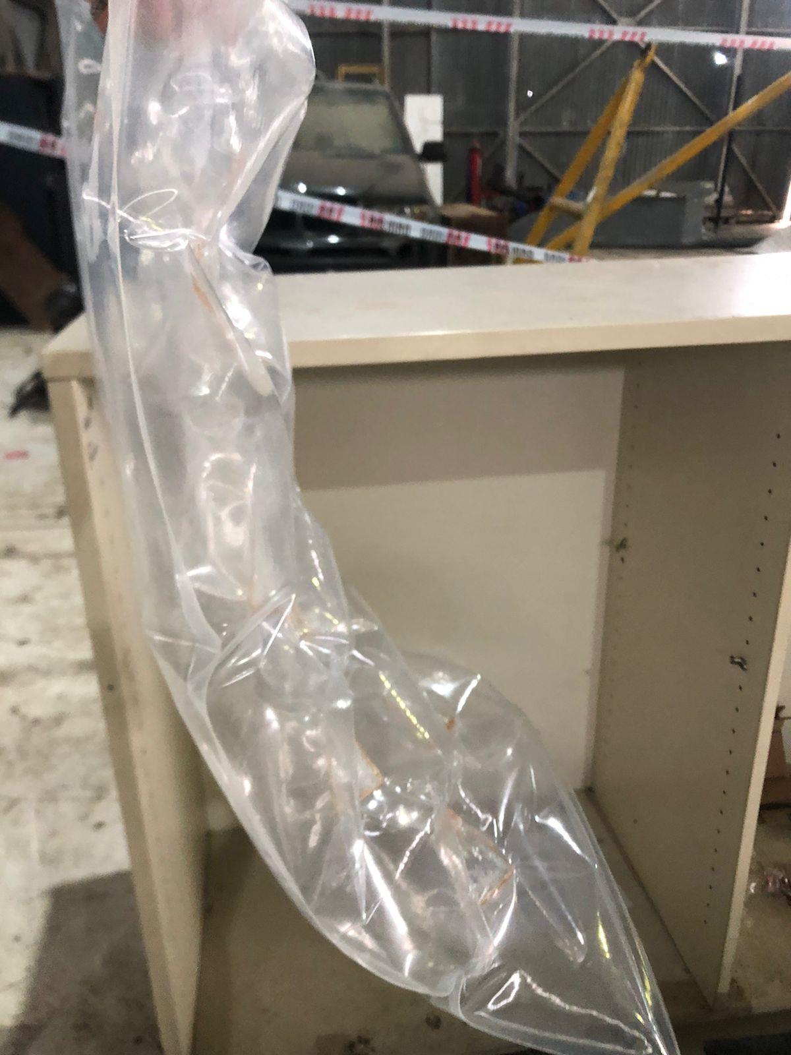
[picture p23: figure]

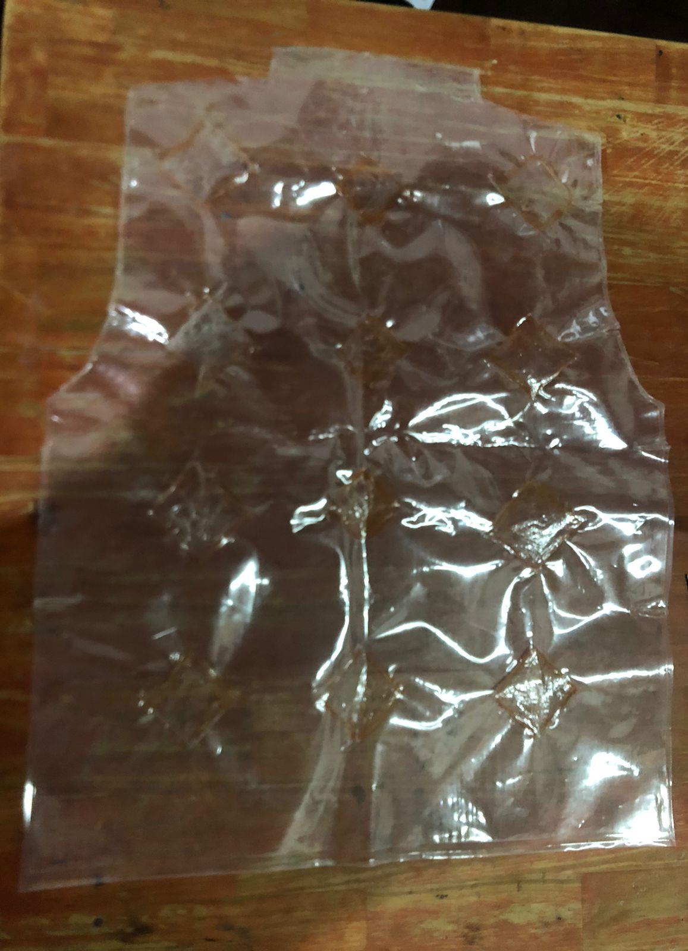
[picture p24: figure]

# Semana 24

08/10/24

- Se hace el informe descriptivo de la competencia de Salud y Bienestar de la ONIET
- Se hacen los primeros esquematicos del circuito
- Primeras placas

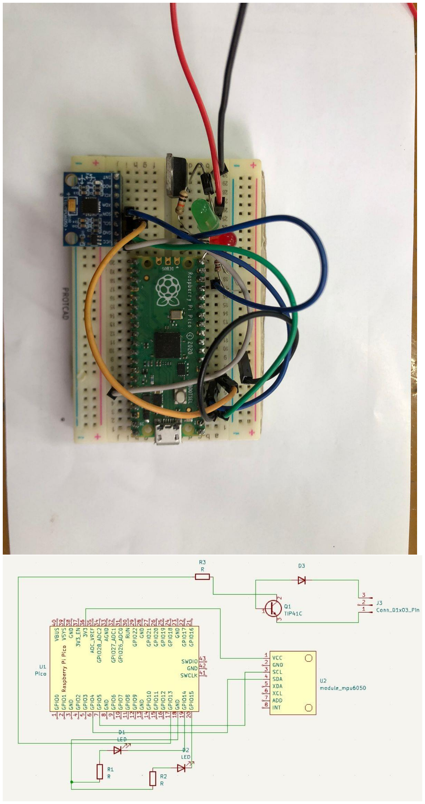
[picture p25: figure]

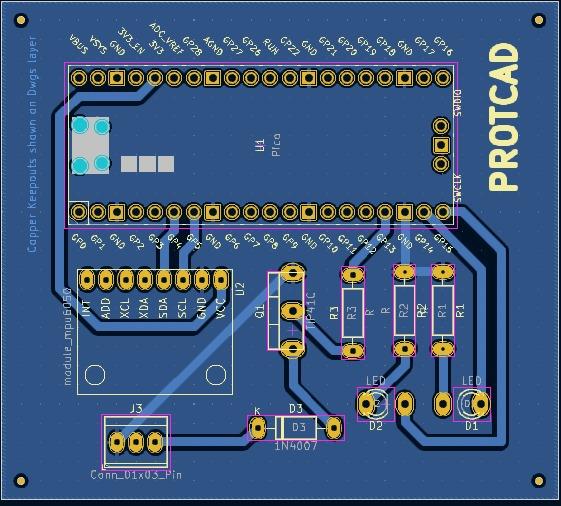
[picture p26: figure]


# Semana 25

14/10/24

- Al quedar nada de ir a la ONIET se estuvo trabajando en total apuro

- Debido a que tardaron en conseguirnos la valvula de agua, al probar el circuito surgieron nuevos problemas que antes no se encontraban presentes, como que los transistor no saturaban correctamente. Esta situacion no seria un gran problema si hubiera pasado hace no mas de una semana, poreso el tiempu juega en contra.
- Se logro abrir la valvula de agua y estamos al problema de que la valvula no reacciona al pin gpio que tiene de la raspberry, por lo tanto no se abre cuando un led se prende.
- Se encontro una forma de abrir el cartucho de Co2 al intruducirlo en la valvula que es como con un clavo interno.
- Se consiguio a su vez un reductor que se adapte al orificio de la valvula y a su vez al del cartucho.

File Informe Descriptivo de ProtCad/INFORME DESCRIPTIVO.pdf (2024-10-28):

# Informe Descriptivo

# Chaleco de Seguridad Automatizado


## Seguridad y Comodidad en Uno


Micaela Lopez Aranan | Dafne Monzon Matos
7° 2da Aviónica | 7° 2da Aviónica
DNI: 46.937.337 | DNI: 47.025.655

Docentes / Tutores:

Carlassara Fabrizzio

Medina Sergio

Fecha de Inicio:

Abril del 2024

Duracion, en Semanas:

28 semanas

Horas de trabajo en Total:

672 horas en total (336 hs. por persona)

Personas Afectadas a lo largo del proyecto:

Participaron 2 personas en un promedio de 24 hs semanales. (12 por persona)

INDICE:

Presentación : | 1
Datos : | 2
Objetivo: ¿Para qué sirve ProtCad? | 3
Alcance Delimitación de Protcad | 3
Temática y Impacto, tanto social como geográfico | 4
| 5
Segmento destino target | 6
Ámbito de incumbencia y su entorno donde se desarrolla | 7
Descripción general del proyecto | 8

Funcionalidades ¿Qué hace ProtCad? | 9
Beneficios de ProtCad y ¿Por qué es buen proyecto? | 10
Descripción Técnica ¿Cómo está hecho ProtCad? | 11
Placas del circuito descripción digital y física | 12

Imagenes:
13
14
| 15

16

## Descripcion:

¿Para qué sirve?

Objetivo de PROTCAD

El objetivo principal de PROTCAD es ofrecer protección, seguridad, tranquilidad y comodidad a personas con alto riesgo de lesiones por caídas. Esto se logra mediante la integración de un sistema de inflado automático, similar al de los airbags en automóviles, que se activa cuando el sensor MPU6050 detecta una inclinación superior a un ángulo determinado, indicando una caída.

Alcance: Delimitar el proyecto, y describir de qué trata:

PROTCAD es un chaleco de protección, diseñado para minimizar el impacto de caídas y prevenir lesiones graves. El chaleco se activa automáticamente al detectar una caída, inflándose de inmediato para proteger áreas clave.

Limitaciones del proyecto:

1. Tamaño único por el momento: Aunque adaptable, actualmente el chaleco está disponible en un solo talle general.
2. Enfoque en usuarios específicos: Está dirigido principalmente a personas con riesgo de caídas, lo que limita su adopción masiva en personas fuera de estos grupos.

3. Costo: El precio de producción estimado es de 140 mil pesos, lo que podría limitar su accesibilidad a ciertos mercados.

El proyecto, aunque en sus fases iniciales, tiene el potencial de ser mejorado con más recursos y tiempo, permitiendo una mayor adaptabilidad y una posible expansión hacia otros sectores o mercados más amplios.

Temática o Impacto, tanto social como geográfico:

Temática o Impacto de PROTCAD: Bienestar y Salud / Inovacion

Impacto Social

PROTCAD tiene un enfoque directo en la seguridad personal y el bienestar de personas vulnerables, brindando protección a quienes tienen un mayor riesgo de sufrir caídas, como adultos mayores, personas en rehabilitación, y aquellos con condiciones médicas que afectan su movilidad. Su impacto social es significativo por varias razones:

1. Prevención de lesiones graves: Al reducir el riesgo de fracturas o daños en la cabeza, la columna y la cadera, PROTCAD contribuye a mejorar la salud y calidad de vida de los usuarios, disminuyendo las posibles secuelas físicas de una caída.
2. Tranquilidad para el usuario y su entorno: Muchas personas, especialmente familiares o cuidadores, viven con la constante preocupación de que un ser querido sufra una caída grave. PROTCAD ofrece una solución que genera confianza y paz mental tanto para los usuarios como para sus seres cercanos.
3. Mejor calidad de vida: El chaleco permite que los usuarios mantengan su independencia y realicen sus actividades cotidianas sin temor a sufrir un accidente. Esto es crucial para mantener la autonomía y reducir la dependencia de terceros, lo cual es particularmente importante para personas mayores.

4. Inclusión: PROTCAD se dirige a diversos grupos que enfrentan dificultades diarias debido a su condición física, creando un dispositivo que ayuda a mejorar la seguridad y el movimiento, dándoles una mayor oportunidad de participación en la sociedad.

Creado en china, desarrollado en EE. UU, disponibles en mercados europeos, america del norte, en Italia, Se espera que su adopción aumente a medida que se vuelvan más accesibles, particularmente en sociedades que envejecen como Japón, Estados Unidos y partes de Europa.

Impacto Geográfico

El impacto geográfico de PROTCAD puede ser relevante tanto a nivel local como global:

5. Impacto Nacional: El proyecto es una innovación que, hasta ahora, no ha sido producida ni distribuida a nivel nacional. Al implementarse en un mercado local, podría cubrir una necesidad significativa en países o regiones con poblaciones envejecidas o con altos índices de enfermedades crónicas que afectan la movilidad, como ocurre en muchos países latinoamericanos, incluido Argentina.
6. Impacto Global: A largo plazo, PROTCAD tiene potencial para expandirse internacionalmente, ya que el envejecimiento de la población es una tendencia mundial, y con ello aumenta el riesgo de caídas y lesiones graves. Países con un mayor porcentaje de personas mayores, como Japón o algunos países de Europa, serían mercados donde este tipo de tecnología podría tener una alta demanda.

Otros Impactos Potenciales

- Sector salud: PROTCAD puede reducir la demanda en los sistemas de salud pública y privada al disminuir el número de hospitalizaciones relacionadas con caídas, fracturas y cirugías resultantes de accidentes en personas mayores o en rehabilitación.
- Innovación tecnológica: Al ser un producto que involucra tecnología avanzada (sensores, válvulas, CO2), PROTCAD impulsa la innovación en el campo de los dispositivos de seguridad personal, contribuyendo al desarrollo de nuevos productos que podrían aplicarse en otras áreas o grupos.

En resumen, el impacto de PROTCAD es amplio tanto a nivel social como geográfico, ofreciendo una solución que responde a una necesidad urgente en la prevención de lesiones graves por caídas, con el potencial de beneficiar a individuos y sistemas de salud tanto local como globalmente.

## Segmento destino (target)

El segmento destino de ProtCad se enfoca principalmente en las siguientes usuarios:

1. Personas mayores de 40 años: A partir de esta edad, los huesos tienden a volverse más frágiles debido a la disminución de la densidad ósea y la pérdida de calcio. Esto las hace más vulnerables a fracturas graves en caso de caídas, especialmente en la cadera. Este grupo es el más susceptible a sufrir consecuencias graves, como dificultades de movilidad, pérdida de independencia, o incluso muerte por complicaciones derivadas de una fractura de cadera.
2. Personas en rehabilitación: Aquellas que se recuperan de una cirugía o lesión y que necesitan protección adicional para evitar recaídas que puedan agravar su estado. ProtCad ofrecería una capa extra de seguridad durante el proceso de recuperación.
3. Personas con condiciones neurológicas como epilepsia, Parkinson o esclerosis múltiple: Estos usuarios están más expuestos a caídas debido a problemas de coordinación y equilibrio que son comunes en estas condiciones.
4. Personas con enfermedades crónicas como osteoporosis o diabetes con neuropatía periférica: Estas condiciones incrementan el riesgo de fracturas o lesiones graves en caso de caídas, lo que convierte a ProtCad en una herramienta de protección valiosa para evitar daños mayores.
5. Personas que cuidan a sus seres queridos: Además de los usuarios directos, este segmento incluye a quienes tienen a su cargo personas mayores o con discapacidades, y que buscan mejorar la seguridad y reducir la ansiedad de cuidar a alguien vulnerable a caídas.

En resumen, ProtCad está dirigido a personas de mediana edad y mayores, así como a aquellos con condiciones médicas específicas que los hacen más propensos a sufrir caídas y lesiones severas.

## Ámbito de incumbencia (entorno donde se desarrolla)

El ámbito de incumbencia de ProtCad se centra en varios entornos clave donde este producto podría desarrollarse y tener impacto:

1) Sector de la salud y rehabilitación: ProtCad se inserta dentro de la atención médica preventiva, especialmente en centros de rehabilitación, hospitales, y clínicas donde se tratan personas con condiciones físicas que las hacen propensas a caídas, como pacientes geriátricos o aquellos en procesos postoperatorios. Además, tiene cabida en instituciones especializadas en neurología para personas con Parkinson, epilepsia o esclerosis múltiple.
2) Hogares de cuidado de ancianos y residencias geriátricas: Los hogares de cuidado, donde la preocupación por caídas es alta, son un entorno esencial para la implementación de ProtCad. En estos espacios, los cuidadores y personal médico buscan maneras de mejorar la seguridad de las personas mayores, y este tipo de tecnología sería un complemento ideal para reducir riesgos.
3) Entornos domésticos: Para personas que envejecen en sus propios hogares, el chaleco ProtCad ofrece una solución práctica para mejorar su seguridad diaria sin comprometer la independencia. Familias que cuidan a personas mayores o con movilidad reducida podrían implementar el producto como una medida preventiva.

4) Mercado de dispositivos de asistencia personal y tecnología vestible (wearables): En el contexto de la tecnología aplicada a la salud, ProtCad se integra dentro del mercado de los wearables o dispositivos inteligentes de protección. Este tipo de chaleco airbag, que combina sensores avanzados con mecanismos automáticos de inflado, puede atraer a personas que buscan productos de alta tecnología para mejorar su calidad de vida.
5) Industrias de protección laboral: Aunque inicialmente se piensa en el sector de la salud, el ámbito laboral para trabajadores de ciertos sectores (construcción, agricultura, etc.) donde el riesgo de caídas es alto también es relevante. ProtCad podría adaptarse a estos entornos, brindando seguridad adicional a los trabajadores.

En resumen, el entorno donde se desarrolla el proyecto abarca el ámbito sanitario, los hogares de cuidado, y el mercado de dispositivos de protección personales, con la posibilidad de expandirse a sectores laborales.

## Descripción general (Explicar el proyecto)

ProtCad es un proyecto innovador que busca desarrollar un chaleco (en principio era un cinturon) de protección tipo airbag, diseñado para activarse en el momento de una caída. Este dispositivo está pensado principalmente para personas mayores o con condiciones médicas que las hagan propensas a caídas, como osteoporosis, Parkinson o problemas de movilidad. El sistema se activa a través de un sensor de movimiento (MPU6050), que detecta la inclinación de la persona y libera aire comprimido para inflar una bolsa que protege la cadera y otras áreas críticas del cuerpo. El objetivo principal es reducir el impacto y el riesgo de lesiones graves, proporcionando seguridad y tranquilidad a los usuarios y sus familias.

## Funcionalidades (Qué hace?)

1. Detección de Caídas: Utiliza un sensor MPU6050 que funciona como giróscopo y acelerómetro para detectar cambios en la posición del usuario, estos son monitoreados continuamente. Cuando el sensor detecta una inclinación que supera los límites predefinidos (indicando una posible caída), activa el sistema de protección.
2. Activación Automática del Airbag: Al detectar una caída, el sistema abre un cartucho de aire comprimido que infla rápidamente una bolsa alrededor de la cadera, amortiguando el impacto y reduciendo el riesgo de lesiones graves.
3. Protección de Zonas Vulnerables: El diseño del chaleco está enfocado en proteger principalmente la cadera, una de las áreas más susceptibles a fracturas en personas mayores o con movilidad reducida, pero también ofrece protección a otras zonas del cuerpo según el diseño.
4. Indicadores Visuales: Dispone de luces LED para indicar el estado del dispositivo y alertar sobre el funcionamiento del sensor, mostrando si un eje (X, Y o Z) ha superado los límites de inclinación.
5. Botón de Encendido y Apagado: Para mayor control, el usuario puede activar o desactivar el dispositivo cuando lo considere necesario.

## Beneficios (Por qué es bueno el proyecto?)

1. Prevención de Lesiones: Al proporcionar un sistema de protección tipo airbag que se activa durante una caída, ProtCad reduce significativamente el riesgo de fracturas en la cadera y otras lesiones graves en personas mayores o con problemas de movilidad, evitando hospitalizaciones prolongadas y complicaciones de salud.
2. Mayor Seguridad y Tranquilidad: Al proteger áreas vulnerables como la cadera, brinda seguridad tanto al usuario como a su entorno cercano (familia, cuidadores), aliviando el miedo y la ansiedad relacionados con caídas.
3. Innovación y Accesibilidad: El uso de sensores y tecnología de inflado rápida permite una solución avanzada y eficiente que no requiere de intervenciones médicas complicadas. Además, su diseño adaptable lo hace accesible para una amplia gama de personas.
4. Mejora de la Calidad de Vida: Al reducir el impacto de las caídas, ProtCad permite que las personas mayores o en rehabilitación puedan moverse con más libertad, confianza e independencia, promoviendo una vida más activa y saludable.
5. Costo Eficiente: En comparación con los costos médicos de tratar fracturas y otros daños, el uso preventivo de ProtCad es una inversión rentable a largo plazo para evitar gastos médicos elevados.

## Descripción Técnica (Cómo está hecho?)

Descripción Técnica de ProtCad:

1. Sensor MPU6050: Este componente es clave para el funcionamiento de ProtCad. Se trata de un giroscopio y acelerómetro de 6 ejes que permite detectar la posición y aceleración del cuerpo. Está constantemente monitoreando los movimientos del usuario, y cuando se detecta una inclinación o caída, envía una señal para activar el sistema de protección.
2. Sistema de Activación por CO2: ProtCad cuenta con un cartucho de CO2 de 25g conectado a una válvula solenoide de agua adabtada a este, que se activa cuando el sensor detecta una caída. La válvula, controlada por una batería y el sistema electrónico, libera el gas comprimido inflando el chaleco de aire, para proteger al usuario.
3. Microcontrolador (Raspberry Pi Pico o ESP32): El microcontrolador procesa la información del sensor MPU6050 y controla el sistema de activación del cartucho de aire. También coordina la apertura de las válvulas, activando los motores cuando se sobrepasan los límites preestablecidos de inclinación en los ejes (X, Y, Z).
4. Plástico de 200 micrones : Las bolsas que se inflan están fabricadas con plástico de 200 micrones , un material ligero pero resistente, diseñado para soportar el impacto y amortiguar la caída.


5. Chaleco: El dispositivo está montado en un chaleco de tela que rodea la cadera, la espalda y cabeza del usuario, permitiendo una protección adecuada. Además, incluye compartimentos para los cartuchos de aire y la batería.


6. Fuente de Alimentación Baterias: Protcad esta alimentado por dos baterías de 9 v.
7. Circuito de Control y Programación en C: Toda la programación del dispositivo se realiza en lenguaje C, con el uso de Visual Studio Code para la programación del sensor, la activación del motor, y la sincronización del inflado.


8. Placas del circuito: El proceso de producción de una placa con su circuito y componentes, comúnmente llamado fabricación de una PCB (Placa de Circuito Impreso) A continuación, se detallan:

A)Diseño del Circuito (CAD)

- Primero se hizo en un protoboard: Donde tambien se probó y verifico que el circuito funcionase.


Diseño esquemático del circuito en software especializado, en nuestro caso usamos KiCAD. En este paso:


Generación de Archivos Gerber


Circuito Impreso en papel fotográfico


Para saber la ubicacion de los componentes:


Fabricación de la PCB, Inserción de Componentes y soldadura
Este proceso involucra la creación física de la placa:

Pruebas y Verificación

Después de ensamblar la placa y sus componentes, se realizan pruebas. Se verifican las conexiones eléctricas (mediante pruebas de continuidad) y se asegura que no haya cortocircuitos ni problemas en las pistas.

Este conjunto de componentes electrónicos y mecánicos garantiza que ProtCad reaccione de manera precisa y rápida ante caídas, proporcionando una protección inmediata en situaciones de alto riesgo para el usuario.

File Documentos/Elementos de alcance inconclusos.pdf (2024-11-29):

## Elementos de alcance inconclusos

Nuestra principal problematica fue trabajar con aire comprimido, si bien hemos llegado a trabajar con aire comprimido en la escuela, tuvimos que adentrarnos en la neumatica el cual no era un campo del que sepamos mucho.
El proyecto no termina de activarse por completo debido a que la valvula de aire que tenemos no es capaz de manejar la presion de los cartuchos, ni la de un compresor de aire. Con esto nos dejo en claro que el mayor problema es la valvula, por lo que una forma de que todo funcione seria reemplazando la valvula que tenemos a disposcion por una valvula de aire que maneje correctamente la presion del aire comprimido. De esta forma ya que todo lo demas funciona correctamente, el chaleco deberia activarse sin problemas.

Otro factor importante en el desarrollo de este proyecto fue la cantidad de integrantes(2), si bien puede llegar a considerarse un proyecto “facil” de desarrollar, la cantidad de integrantes influyo mucho en la distribución de tareas y en la falta de atencion en algunas otras(Como nuestra cuenta de instagram, la cual dejamos muy desatendida).

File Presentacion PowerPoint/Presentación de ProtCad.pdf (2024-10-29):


# Presentación de ProtCad

PROTCAD

NUESTRO PROYECTO


# INTRODUCCIÓN

Nosotras desarrollamos un sistema de seguridad automatico llamado ProtCad este es un chaleco y su objetivo principal es ofrecer protección, seguridad, tranquilidad y comodidad a personas con alto riesgo de lesiones por caídas.

PROTCAD

# PROBLEMA O NECESIDAD IDENTIFICADA

PROTCAD

las caídas de personas mayores o con condiciones que afectan su movilidad. Estas caídas son comunes y pueden causar lesiones graves, como fracturas en la cadera, que afectan la calidad de vida y pueden llevar a hospitalizaciones prolongadas.

Problemas clave:
Lesiones Graves / Muerte: Las caídas pueden resultar en fracturas y otros daños que limitan la movilidad y la independencia.

1.

Miedo y Ansiedad: Muchas personas mayores y sus familias viven con el miedo constante de que una caída pueda causar un accidente grave.

2.

Dependencia Aumentada: Después de una caída, algunas personas necesitan más ayuda, lo que puede afectar su autonomía.

3.

Costos Médicos: Las lesiones por caídas generan gastos altos en tratamientos médicos y hospitalizaciones.

4.

## 50 Años (% de Lesiones por Caídas)

# GRÁFICOS

50 Años; 60 Años; 70 Años; ESTADÍSTICAS

Años (% de Lesiones por Caídas)


Lesiones: Aproximadamente el 30-40% de las personas mayores de 65 años sufren caídas anualmente, y un porcentaje considerable de estas caídas resultan en lesiones.
Muertes: Las caídas son una de las principales causas de muerte accidental en personas mayores. En Estados Unidos, por ejemplo, se estima que alrededor de 36,000 personas mayores mueren anualmente debido a caídas.

PROTCAD

# INFORMACION IMPACTANTE QUE RESPALDA



# PROTCAD NUESTRA

DETECCIÓN RÁPIDA
DE CAÍDAS:

INFLADO AUTOMÁTICO DEL
AIRBAG:

PROTECCIÓN DE ÁREAS
CRÍTICAS:

# SOLUCION

"No se trata de lo que te sucede, sino de cómo reaccionas a lo que te sucede."

Utiliza el sensor MPU6050
para monitorear
continuamente la
posición y aceleración del usuario. Al detectar una
inclinación que indica
una caída, el sistema se
activa de inmediato.

Al activarse, un cartucho
de CO2 infla
rápidamente una bolsa
protectora alrededor de
áreas vulnerables, como
la cadera, amortiguando
el impacto y reduciendo
el riesgo de lesiones
graves.

El diseño del chaleco
está enfocado en
proteger las zonas más
susceptibles a
fracturas, lo que ayuda
a prevenir lesiones
graves en caso de
caídas.

SEGURO DE HOGAR; proporciona seguridad tanto al usuario como a sus familiares, aliviando la ansiedad relacionada con las caídas y fomentando la independencia en las actividades diarias.; TRANQUILIDAD PARA USUARIOS

1 | 2 | 3 | 4

PROTCAD

# OBJETIVOS

Dar protección, seguridad, minimizar el riesgo de lesiones graves por caídas en personas mayores y con
condiciones de movilidad reducida, mejorando así su seguridad y calidad de vida.

Prevención de Lesiones:Que nuestros usuarios puedan tener una mejor
calidad de vida.

Detección Precisa de Caídas: Tener un sistema seguro y con la mejor presicion.

Facilitar la Independencia

Tranquilidad para Cuidadores y Familiares

01

02

03

04

### 05 Evaluación y Mejora Continua


PROTCAD

# PÚBLICO OBJETIVO

porcentaje de la poblacion que tiene 75 años o mas.

## DE LA POBLACIÓN

15,7%

# COSTOS


PROTCAD

En Japon venden este producto por su gran poblacion de adultos mayores, en europa y Estados unidos tambien, en argentina sale aprox $ 1.000.000

# DESCRIPCION TECNICA

PROTCAD


## MPU6050:

CUENTA CON UN GIROSCOPO CON 3 EJES Y UN ACELEROMETRO DE 3 EJES.


## RASPBERRY PICO: (https://www.amazon.com/raspberry-pico/s?k=raspberry+pico)

TRABAJAMOS CON UN
CODIGO DE LENGUAJE EN C

@Dafne_0258; INTEGRANTES:; @Mica_lop17

PROTCAD

INSTAGRAM DEL PROYECTO:

## @ProtCad


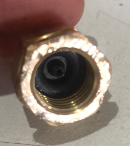
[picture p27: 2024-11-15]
Captura de pantalla 2024-11-15 103043.png

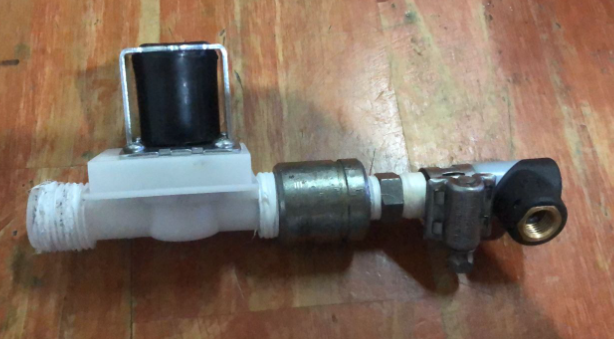
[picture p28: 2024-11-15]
Captura de pantalla 2024-11-15 093851.png

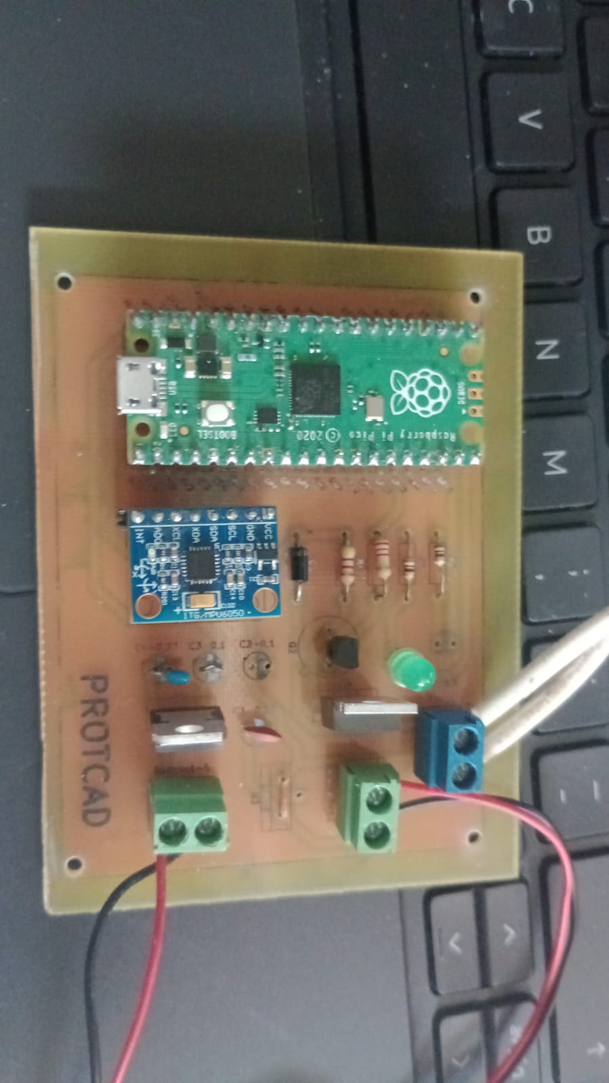
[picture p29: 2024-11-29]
Circuitos/Placa ProtCad.jpg

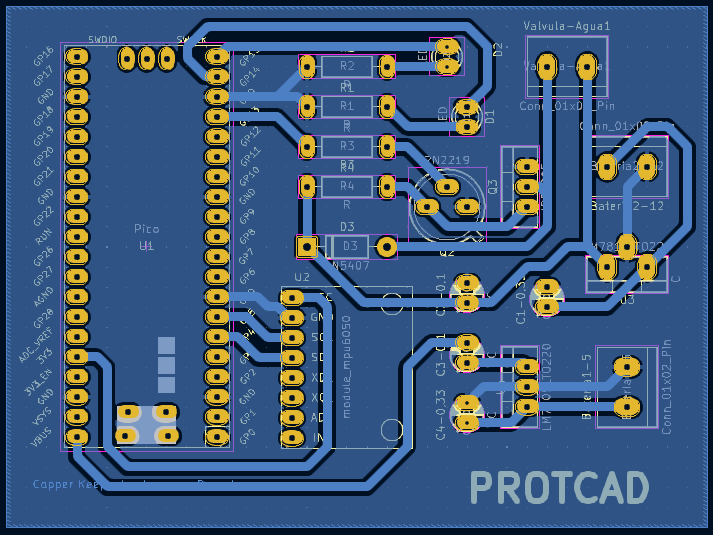
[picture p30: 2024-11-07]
Circuitos/PCB/PCB.png

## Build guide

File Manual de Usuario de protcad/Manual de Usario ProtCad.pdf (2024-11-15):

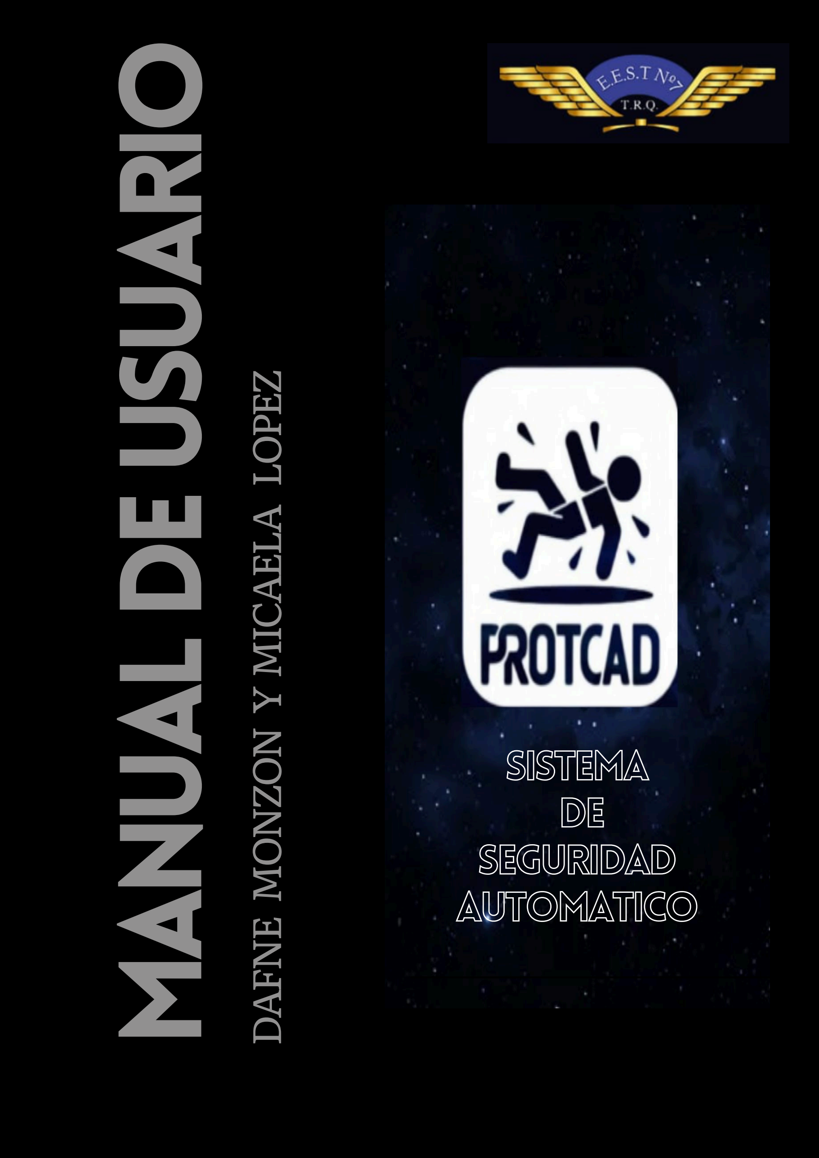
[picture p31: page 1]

# MANUALDEUSUARIO

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
# DAFNE MONZON Y MICAELA LOPEZ

01
02
03
04
05
06

### INTRODUCCION

### OBJETIVO Y PROPOSITO

### FUNCIONAMIENTO PARA SU USO Y ADVERTENCIAS

### SEGURIDAD Y REPUESTOS

### MANTENIMIENTO

### PREGUNTAS FRECUENTES

# ÍNDICE

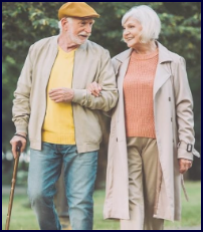
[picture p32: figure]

I

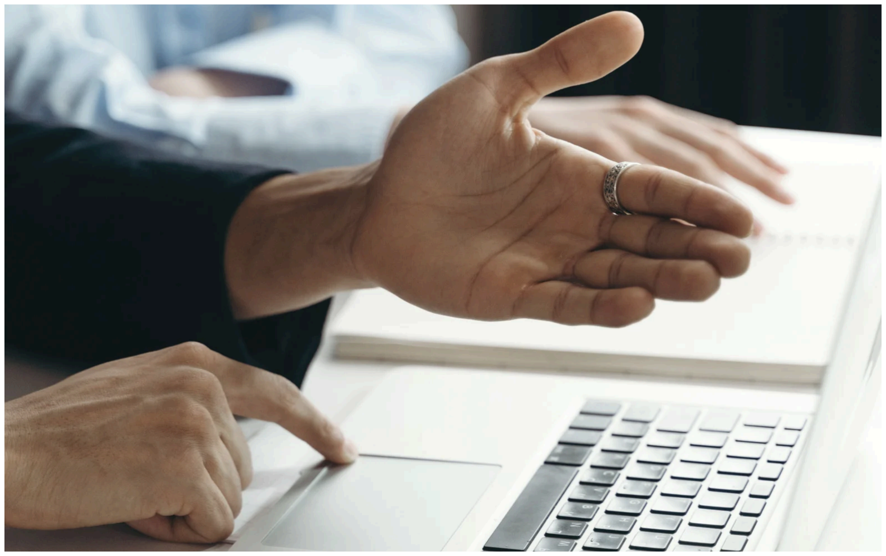
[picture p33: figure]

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
El chaleco PROTCAD utiliza tecnología de sensores avanzados, para detectar caídas y activar automáticamente un sistema de inflado que protege áreas críticas del cuerpo, como la cadera, Su objetivo es reducir significativamente el riesgo de lesiones graves, ofreciendo tranquilidad y seguridad tanto al usuario como a sus familiares o cuidadores.

BIENVENIDO AL MANUAL DE USUARIO DE PROTCAD, UN CHALECO INNOVADOR DISEÑADO PARA OFRECER UNA PROTECCIÓN AVANZADA CONTRA CAÍDAS, IDEAL PARA PERSONAS CON ALTO RIESGO DE LESIONES DEBIDO A CONDICIONES MÉDICAS O ENVEJECIMIENTO.

Este manual está diseñado para guiarte en la correcta utilización y mantenimiento de PROTCAD,
asegurando que puedas
aprovechar al máximo sus
funcionalidades y garantizar una protección óptima en todo
momento.
Recuerda que PROTCAD es una herramienta complementaria para mejorar la seguridad y autonomía de las personas vulnerables, pero no reemplaza el cuidado médico ni la supervisión adecuada.

# OBJETIVOYPROPOSITO

PROTCAD : SEGURIDAD Y
COMODIDAD EN UNO

Objetivo Principal:

El objetivo principal de PROTCAD es proporcionar una protección efectiva contra caídas, reduciendo el riesgo de lesiones graves, especialmente en áreas vulnerables del cuerpo como la cadera.
Utilizando tecnología avanzada de sensores y un sistema de inflado automático, PROTCAD ayuda a prevenir fracturas y otros daños derivados de caídas, garantizando mayor seguridad y tranquilidad tanto para el usuario como para sus seres cercanos.

Propósitos Específicos:

1. Protección Inmediata: Detectar de manera precisa e instantánea las caídas a través de un sensor MPU6050, activando el sistema de inflado para proteger al usuario en cuestión de milisegundos.
2. Seguridad y Confianza: Brindar a los usuarios, especialmente a personas mayores o con condiciones de movilidad reducida, la confianza para realizar sus actividades cotidianas con mayor seguridad, reduciendo la ansiedad tanto del usuario como de sus cuidadores o familiares.
3. Comodidad y Autonomía:
Permitir que el usuario mantenga su independencia y calidad de vida, al tiempo que se minimizan los riesgos asociados a caídas. El chaleco es ligero, adaptable y cómodo, diseñado para usarse durante todo el día sin interferir en el movimiento.
4. Prevención de Lesiones Graves: Disminuir la gravedad de las lesiones causadas por caídas, especialmente en personas
propensas a fracturas o
contusiones severas, como los adultos mayores o aquellos en procesos de rehabilitación o con condiciones como la epilepsia o desmayos.
5. Fácil Uso y Mantenimiento: Facilitar la activación, el control y el mantenimiento del dispositivo para que los usuarios puedan operarlo sin dificultad y
mantenerlo en condiciones
óptimas a lo largo del tiempo.

1. caja negra:
abrir la caja donde se encuentra el circuito y la valvula
que se encuentra en la parte media del frente del chaleco, en la derecha.
2. cartuchos:
agarrar un cartucho y colocarle la goma de seguro alrededor

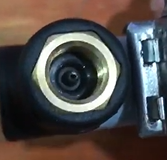
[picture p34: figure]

del mismo, para evitar quemarse del frio que este puede producir. Luego colocar un cartucho ya sea de 20g o 16g en la entrada de flujo de aire de la valvula como la que se ve en la imagen de la derecha, enroscar el cartucho asta que haga tome con el
perforador y terminar de enroscarlo hasta que se perfore.
3. boton y uso:
prender el sistema apretando el boton de encendido luego de haberse colocarse el chaleco, y esta en condiciones para su uso.

### advertencias:

No sumergir en agua.

Uso Exclusivo: ProtCad está diseñado para personas mayores de 40 años o personas con condiciones médicas específicas que las hacen más propensas a caídas (por ejemplo, osteoporosis, Parkinson, esclerosis múltiple, etc.).

No Usar en Situaciones No Recomendadas: ProtCad no está diseñado para actividades extremas ni para ser usado en entornos donde el riesgo de caídas sea mínimo o controlado.

# FUNCIONAMIENTO PARASU USOYADVERTENCIAS

SEGURIDAD:

CHEQUEOS REGULARES: REALICE VERIFICACIONES PERIÓDICAS PARA ASEGURARSE DE QUE TODOS LOS SISTEMAS, ESPECIALMENTE LOS SENSORES Y LAS BATERÍAS, ESTÉN FUNCIONANDO CORRECTAMENTE. CHEQUEAR CADA 1 MES Y MEDIO APROX

CONSULTA MÉDICA: AUNQUE PROTCAD ESTÁ DISEÑADO PARA OFRECER PROTECCIÓN ADICIONAL, NO REEMPLAZA LA SUPERVISIÓN MÉDICA O EL USO DE DISPOSITIVOS DE ASISTENCIA RECOMENDADOS POR SU MÉDICO.

1

# SEGURIDAD

Y

# REPUESTOS

2

REPUESTOS:

LOS CARTUCHOS DE CO2 SE PUEDEN CONSEGUIR FACILMENTE LOS DE 16G SUELEN VENDERSE EN BICICLETERIAS Y LOS DE 20G QUE SON UN POCO MAS GRANDES SE PUEDEN PEDIR EN MERCADO LIBRE

1

### Mantenimiento del ProtCad:

### Reemplazo de las Baterías:

El ProtCad funciona con dos baterías de 9V.

### Para reemplazarlas, abra el compartimento de la batería en la parte posterior del chaleco, retire

las baterías usadas y coloque las nuevas,

### asegurándose de conectar los terminales

correctamente.

### Tambien es posible que si un cartucho esta durante mucho tiempo deba cambiarce (si esta por mas de 3 meses por ejemplo) se debera reponer el cartucho de 16 o 20g (los cartuchos no son reuitilizables por lo que son de un solo uso)

# MANTENIMIENTO

N/P

## CONTÁCTANOS

numero: 1156346434 1133287030 gmail: protcad148@gmail.com

1: ¿CÓMO SÉ SI EL PROTCAD ESTÁ FUNCIONANDO CORRECTAMENTE?

CUANDO PROTCAD ESTÁ FUNCIONANDO CORRECTAMENTE, LA LUZ LED VERDE Y ROJA SE ENCENDERAN SIN PROBLEMA YA QUE MUESTRA QUE DETECTA UNA CAIDA, SI NO SE ENCIENDE A PESAR DEL MOVIMIENTO DE PASAR X GRADOS CON INCLINACION ES PORQUE NO ESTA FUNCIONANDO Y PUEDE QUE NO TENGA BATERIA SI DESP DE CAMBIAR LAS BATERIAS NO ENCIENTE, DEBERA MANDARSE A UN TECNICO.

2: ¿CUÁNTO TIEMPO DURA LA BATERÍA DEL PROTCAD?

LA DURACIÓN DE LAS BATERÍAS DEPENDE DEL USO, PERO SE RECOMIENDA CAMBIARLAS AL MENOS UNA VEZ AL MES PARA ASEGURAR UN FUNCIONAMIENTO ADECUADO.

3:¿PUEDO USAR EL PROTCAD DURANTE ACTIVIDADES DEPORTIVAS O DE ALTA INTENSIDAD?

PROTCAD ESTÁ DISEÑADO PRINCIPALMENTE PARA PERSONAS CON RIESGO DE CAÍDAS EN SU VIDA DIARIA. NO SE RECOMIENDA SU USO EN ACTIVIDADES EXTREMAS O DEPORTIVAS SIN LA SUPERVISIÓN DE UN PROFESIONAL.

4: ¿CÓMO PUEDO REEMPLAZAR EL CARTUCHO DE CO2 DESPUÉS DE UNA CAÍDA?

DIRÍGETE AL CENTRO DE SERVICIO AUTORIZADO PARA REEMPLAZAR EL CARTUCHO DE CO2 O SIGUE LAS INSTRUCCIONES DEL FABRICANTE PARA HACERLO DE MANERA SEGURA.

## Preguntas Frecuentes )

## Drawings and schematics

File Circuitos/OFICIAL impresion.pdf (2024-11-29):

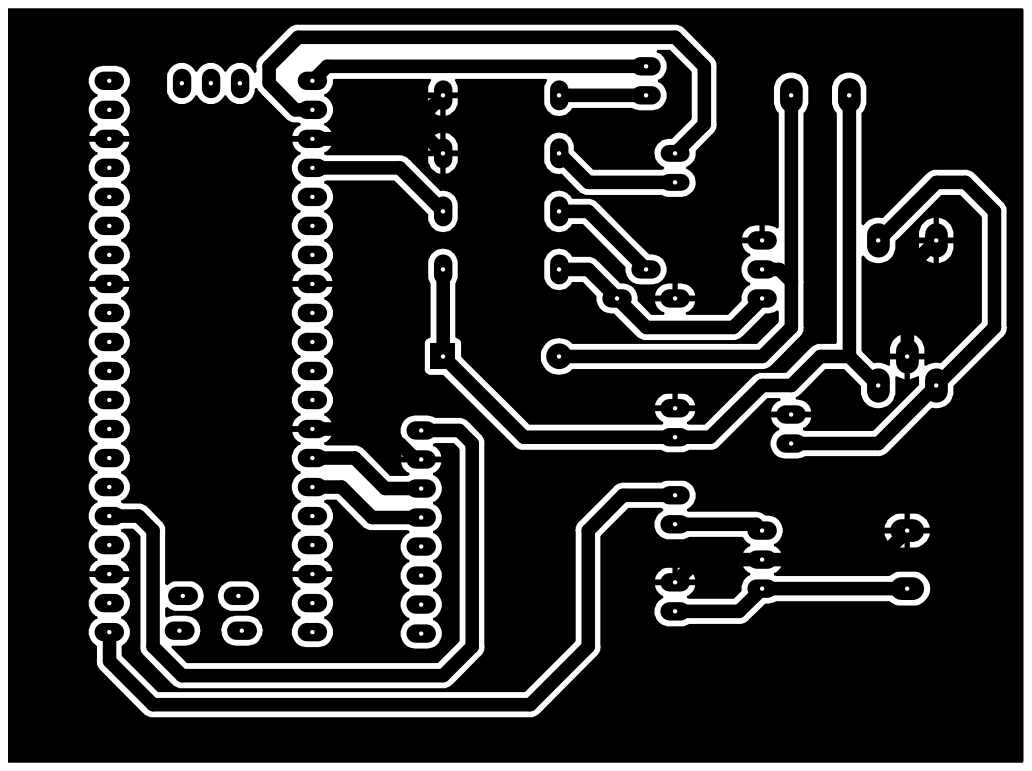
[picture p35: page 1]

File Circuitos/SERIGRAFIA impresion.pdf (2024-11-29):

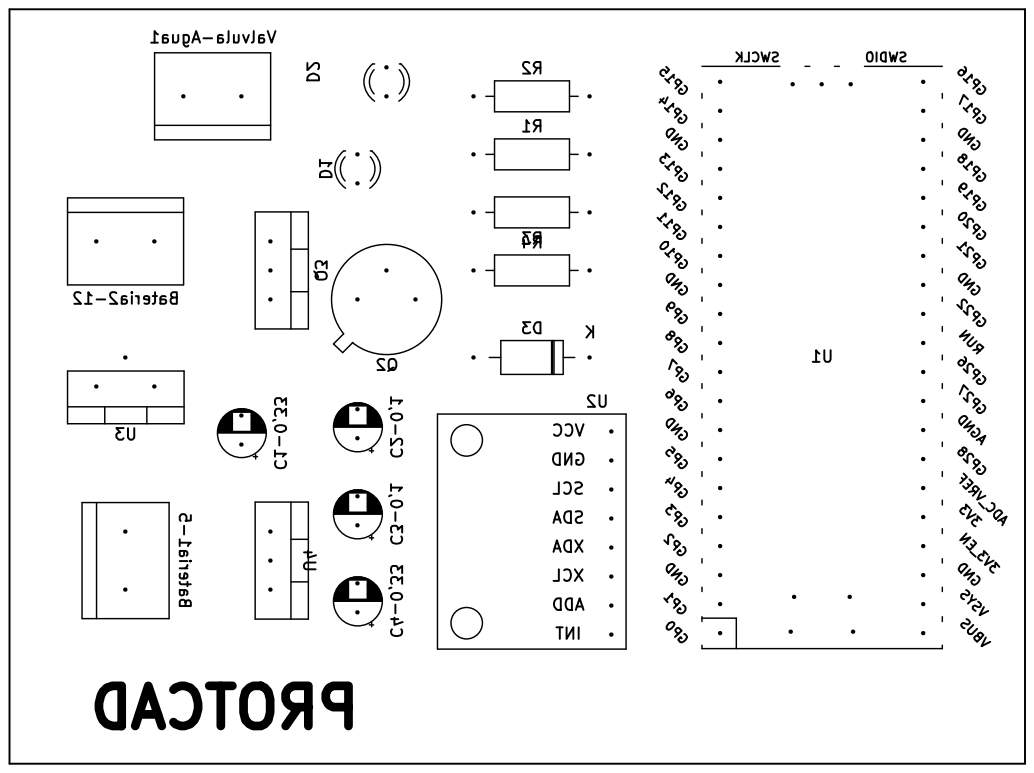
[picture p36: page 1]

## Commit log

2024-10-23 feat: Informacion impactante que respalda
2024-10-23 feat: Nuestra Solucion (de ProtCad)
2024-10-24 feat : Disponibilidad en el exterior
2024-10-24 feat: Ámbito de incumbencia
2024-10-25 Create Sistema de Abertura
2024-10-28 feat: añado carpeta de Docs y archivo de serigrafia
2024-10-28 fix: Cambiar nombre de Serigrafia a Carpeta de Campo
2024-10-28 Feat: Agregar Area de Carpeta Tecnica
2024-10-28 Fix: Mover la carpeta tecnica a carpeta de documentos
2024-10-28 feat: agregar documento de anteproyecto
2024-10-28 Fix: Cambiar Nombre de Carpeta Tecnica a Carpeta de Campo
2024-10-28 Fix: Corregir formato Carpeta de campo
2024-10-29 feat: Presentacion PowerPoint
2024-11-07 feat: Agregar carpeta de circuitos pistas y serigrafia
2024-11-07 fix: Borrar carpeta de circuitos con serigrafia y pistas
2024-11-07 Feat: Agregar carpeta de circuitos y Serigrafia
2024-11-07 Feat: Agregar Archivo de serigrafia
    [Serigrafia.kicad_sch]
2024-11-07 Feat: Agregar serigrafia en pdf a circuitos
    [Serigrafia.kicad_sch]
2024-11-07 Fix: Cambiar nombre de "Serigrafia" a "Diagrama de circuito"
2024-11-07 Feat: Agregar Pcb
2024-11-07 Fix: Mover Diagrama de circuito a carpeta de PCB
2024-11-07 Feat: Agregar Readme para carpeta de circuitos
2024-11-07 Feat: Agregar fila de banner
2024-11-08 Fix: Eliminar fila de banner
2024-11-08 Feat: Agregar foto de banner ProtCad
2024-11-08 Fix: Cambiar nombre de diagrama de circuito a circuito esquematico
2024-11-08 Feat: Agregar fila de serigrafia impresion
2024-11-08 Fead: Agregar carpeta de codigos con codigo del circuito
2024-11-08 Fix: Cambiar el codigo los limites y las reaciones de los leds y la valvula
    [main.c]
2024-11-15 Feat: Agregar Guion de video
2024-11-15 Fix: Eliminar fila de carpeta de campo
2024-11-15 feat: imagen del sistema de abertura N°1
    funcionaba mas que nada con cartuchos solo de 16g
2024-11-15 feat: imagen del sistema de abertura N°2
    se hicieron cambios para que las piezas de plastico sean de acero y resistentes a mayor presion
2024-11-15 feat: imagen del sistema de abertura N°3
    desarme el perforador de bicicleta para encotrar el problema
2024-11-15 feat: imagen del sistema de abertura N°4
    perforador que reutilizaremos, es de bronce
2024-11-15 feat: Manual de Usuario protcad
2024-11-15 feat: Manual para usuarios
    explicacion de como usar el producto que ofrece protcad
2024-11-15 feat: Manual de Usuario de Protcad
    Manual de usuario oficial para utilizar el producto que ofrece Protcad
2024-11-29 Fead: Actualizar carpeta de campo
2024-11-29 Feat: Eliminar guion del video que no se uso al final
2024-11-29 Fead: Borrar linea de carpeta tecnica
2024-11-29 Add: Agregar elementos de alance inconclusos
2024-11-29 Feat: Agregar foto de la placa
2024-11-29 fix: Eliminar fila de seriagrafia
